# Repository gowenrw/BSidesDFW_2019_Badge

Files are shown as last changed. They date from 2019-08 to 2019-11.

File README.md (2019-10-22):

# BSidesDFW_2019_Akira_Badge

This is where all the files for the BSidesDFW 2019 Akira Badge will be stored.  
This includes code and art and cad and fab files.  All the things.

## File Structure

This is the file structure of this repository

* [/](/README.md) - YOU ARE HERE
* [/eda/](./eda/) - Electronic Design Automation files for the badge PCB (EDA is KiCad)
  * ./BSidesDFW_2019/ - KiCad 5.x project folder for the BSidesDFW 2019 badge
  * ./HHV_2019_SC/ - KiCad 5.x project folder for the HHV Soldering Challenge board
  * ./CH552G_dev_board/ - KiCad 5.x project folder for the CH552G development board
* [/code/](./code/) - Code for programming the badge
  * ./BSidesDFW_badge/ - Code for the BSidesDFW_2019_Badge
  * ./CH552G_dev_board/ - Code for the CH552G dev board
  * ./CH552T_dev_board/ - Code for the CH552T dev board designed by WrickertH552    
  * ./ugly_dev_board/ - Code for the Ugly Dev Board CH552 Proof of Concept
  * ./include/ - Includes for the 55X chipset used in all the above
* [/docs/](./docs/) - Documentation created by this project related to the badge
* [/graphics/](./graphics/) - Artwork and other graphics created by this project for the badge
* [/reference/](./reference/) - Documentation pulled from other sources related to the badge components
  * ./battery-holder/ - Reference Materials related to battery holders.
  * ./button/ - Reference Materials related to buttons.
  * ./capacitor/ - Reference Materials related to capacitors.
  * ./ch55x/ - Reference Materials related to the CH55x micro-controller.
  * ./LED/ - Reference Materials related to LEDs.
  * ./resistor/ - Reference Materials related to resistors.
  * ./switch/ - Reference Materials related to the switches.
  * ./USB-connector/ - Reference Materials related to USB connectors.
* ./README.md - This File
* ./LICENSE - Currently set to MIT but open to changing it

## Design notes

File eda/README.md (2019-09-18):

# BSidesDFW_2019_Badge / Electronic Design Automation

This is where all the Electronic Design Automation files for the badge PCB will be stored.
The EDA used for this badge is KiCad 5.x

The KiCad projects have been configured to use local libraries for long term sustainability per the best practices listed [HERE](https://hackaday.com/2017/05/18/kicad-best-practises-library-management/) and elsewhere.

## File Structure

This is the file structure of this repository

* [/](/README.md) - Home
* [/eda](/eda/) - YOU ARE HERE
  * [/eda/BSidesDFW_2019/](/eda/BSidesDFW_2019/) - KiCad 5.x project folder for the BSidesDFW 2019 badge
    * ./3d_models/ - This directory contains footprint 3d model files
    * ./gerber/ - This directory contains gerber formatted files for manufacturing
    * ./lib_fp/ - This directory contains footprint module directories
    * ./lib_sh/ - This directory contains schematic library files
    * ./pdf/ - This directory contains pdf prints of schematics and cad files
  * [/eda/CH552G_dev/](/eda/CH552G_dev/) - KiCad 5.x project folder for the CH552G development board
    * ./3d_models/ - This directory contains footprint 3d model files
    * ./gerber/ - This directory contains gerber formatted files for manufacturing
    * ./lib_fp/ - This directory contains footprint module directories
    * ./lib_sh/ - This directory contains schematic library files
    * ./pdf/ - This directory contains pdf prints of schematics and cad files
  * [/eda/HHV_2019_SC/](/eda/HHV_2019_SC/) - KiCad 5.x project folder for the HHV Soldering Challenge board
    * ./3d_models/ - This directory contains footprint 3d model files
    * ./gerber/ - This directory contains gerber formatted files for manufacturing
    * ./lib_fp/ - This directory contains footprint module directories
    * ./lib_sh/ - This directory contains schematic library files
    * ./pdf/ - This directory contains pdf prints of schematics and cad files

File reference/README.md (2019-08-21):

# BSidesDFW_2019_Badge / Reference

Documentation pulled from other sources related to the badge components

## File Structure

This is the file structure of this repository

* [/](/README.md) - Home
* [/reference/](/reference/) - YOU ARE HERE
  * [/reference/battery-holder/](/reference/battery-holder/) - Reference Materials related to battery holders.
  * [/reference/button/](/reference/button/) - Reference Materials related to buttons.
  * [/reference/capacitor/](/reference/capacitor/) - Reference Materials related to capacitors.
  * [/reference/ch55x/](/reference/ch55x/) - Reference Materials related to the CH55x micro-controller.
  * [/reference/LED/](/reference/LED/) - Reference Materials related to LEDs.
  * [/reference/resistor/](/reference/resistor/) - Reference Materials related to resistors.
  * [/reference/switch/](/reference/switch/) - Reference Materials related to the switches.
  * [/reference/USB-connector/](/reference/USB-connector/) - Reference Materials related to USB connectors.

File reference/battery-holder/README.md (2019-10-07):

# BSidesDFW_2019_Badge / Reference / Battery Holders

Battery Holders tested and the one chose for use with the badge.

## File Structure

This is the file structure of this repository

* [/](/README.md) - Home
* [/reference/](/reference/) - Documentation pulled from other sources related to the badge components
  * [/reference/battery-holder/](/reference/battery-holder/) - YOU ARE HERE

## Reference Files

* 3xAAA/No.7 Battery Box with lead wires
  * Tested and CHOSEN for the badge as it provided the needed voltage and stored power
  * [LCSC.COM Reference](./MIC-No-7-Battery-3Section-side-by-side-battery-box-Line-length150mm_C9091_lcsc.com.pdf)
  * [Datasheet](./MIC-No-7-Battery-3Section-side-by-side-battery-box-Line-length150mm_C9091_datasheet.pdf)
* CR2032 Battery Holder SMD
  * Tested and NOT chosen as it did not provide enough voltage and stored power for the badge
  * [LCSC.COM Reference](./Q-J-CR2032-BS-6-1_C70377_lcsc.com.pdf)
  * [Datasheet](./Q-J-CR2032-BS-6-1_C70377_datasheet.pdf)
* CR2032 Battery Holder THT
  * Tested and NOT chosen as it did not provide enough voltage and stored power for the badge
  * [LCSC.COM Reference](./Q-J-CR2032-BS-2-1_C70376_lcsc.com.pdf)
  * [Datasheet](./Q-J-CR2032-BS-2-1_C70376_datasheet.pdf)
  * [SamacSys EDA Schematic/Footprint/Model](./Q-J-CR2032-BS-2-1_LIB.zip)

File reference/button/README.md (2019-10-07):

# BSidesDFW_2019_Badge / Reference / Buttons

Buttons a.k.a Tactile Switches tested and the one chose for use with the badge.

## File Structure

This is the file structure of this repository

* [/](/README.md) - Home
* [/reference/](/reference/) - Documentation pulled from other sources related to the badge components
  * [/reference/button/](/reference/button/) - YOU ARE HERE

## Reference Files

* Shou Han TS2306A Micro Switch
  * Tested and CHOSEN for the badge as it's small form factor and simple design made it perfect for the badge
  * [LCSC.COM Reference](./1904241742_SHOU-HAN-TS2306A-240gf-MSM-9_C388290_lcsc.com.pdf)
  * [Datasheet](./1904241742_SHOU-HAN-TS2306A-240gf-MSM-9_C388290_datasheet.pdf)
  * [SamacSys EDA Schematic/Footprint/Model](./LIB_TS2306A-240GF-MSM-9_C388290.zip)
* Bright TSA363G25 Tactile Switch
  * Tested and NOT chosen as it's larger form factor was not a good fit
  * [LCSC.COM Reference](./1904261730_BRIGHT-TSA363G25-250B_C354943_lcsc.com.pdf)
  * [Datasheet](./1904261730_BRIGHT-TSA363G25-250B_C354943_datasheet.pdf)
* Shou Han THT Tactile Switch
  * Tested and NOT chosen as it's larger form factor was not a good fit
  * [LCSC.COM Reference](./1905211531_SHOU-HAN-TS665CJ_C393938_lcsc.com.pdf)
  * [Datasheet](./1905211531_SHOU-HAN-TS665CJ_C393938_datasheet.pdf)

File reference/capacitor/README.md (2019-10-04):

# BSidesDFW_2019_Badge / Reference / Buttons

Capacitors tested and the one chose for use with the badge.

## File Structure

This is the file structure of this repository

* [/](/README.md) - Home
* [/reference/](/reference/) - Documentation pulled from other sources related to the badge components
  * [/reference/capacitor/](/reference/capacitor/) - YOU ARE HERE

## Reference Files

* Walsin Tech Corp 1206 100nF (0.1uF)
  * Tested and CHOSEN for the badge as it's form factor and capacitance works for the badge
  * [LCSC.COM Reference](./1811301232_Huaxin-S-T-1206B104K251CT_C338139_100nF_lcsc.com.pdf)
  * [Datasheet](./1811301232_Huaxin-S-T-1206B104K251CT_C338139_100nF_datasheet.pdf)
* CCTC 0805 100nF (0.1uF)
  * Tested and NOT chosen as it's smaller form factor was not a good fit
  * [LCSC.COM Reference](./1901071511_CCTC-TCC0805X7R104M500DT_C360619_lcsc.com.pdf)
  * [Datasheet](./1901071511_CCTC-TCC0805X7R104M500DT_C360619_datasheet.pdf)
* Walsin Tech Corp 1206 1uF
  * Tested and NOT chosen as it's capacitance was much higher than required
  * [LCSC.COM Reference](./Huaxin-S-T-1206B105K160_C152974_lcsc.com.pdf)
  * [Datasheet](./Huaxin-S-T-1206B105K160_C152974_datasheet.pdf)

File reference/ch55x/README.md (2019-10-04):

# BSidesDFW_2019_Badge / Reference / CH55x

Reference Materials related to the CH55x micro-controller.

## File Structure

This is the file structure of this repository

* [/](/README.md) - Home
* [/reference/](/reference/) - Documentation pulled from other sources related to the badge components
  * [/reference/ch55x/](/reference/ch55x/) - YOU ARE HERE

## Information

Basics on the CH551:
* 8051 Kernel with most standard registers, commands etc. only 10-15x
* Integrated oscillator up to 24Mhz
* 3x timer
* 2x 8bit PWM
* 1x SPI master / slave
* 2x UART
* 4x ADC 8bit
* 6x touch input
* 16K ROM
* 1K xRAM
* 256b iRAM
* Integrated 3.3V voltage regulator
* Integrated USB device
* 5V or 3.3V operation
* i2c is no problem with bitbanging

Programming is either with Keil C51 or with SDCC (links below)

## Reference Files

* Jiangsu Qin Heng CH552G
  * Tested and CHOSEN for the badge as it's form factor and pin count works for the badge
  * [LCSC.COM Reference](./1812131556_Jiangsu-Qin-Heng-CH552G_C111292_lcsc.com.pdf)
  * [Datasheet CN](./1812131556_Jiangsu-Qin-Heng-CH552G_C111292_datasheet.pdf)
  * [Datasheet EN](./1812131556_Jiangsu-Qin-Heng-CH552G_C111292_datasheet_zh-CN-en-Translated.pdf)
* Jiangsu Qin Heng CH552T
  * Tested and NOT chosen as it's smaller form factor was not a good fit
  * [LCSC.COM Reference](./Jiangsu-Qin-Heng-CH552T_C111367_lcsc.com.pdf)
  * [Datasheet CN](./Jiangsu-Qin-Heng-CH552T_C111367_datasheet.pdf)
  * [Datasheet EN](./Jiangsu-Qin-Heng-CH552T_C111367.zh-CN.en.pdf)

## External References

* [Hackaday article on CH552](https://hackaday.com/tag/ch552/)
* [Blog site with details on CH552](http://atcnetz.blogspot.com/2019/02/ch552-020-mikrocontroller-mit-usb.html)
* [CH55X Android Programmer](https://play.google.com/store/apps/details?id=com.atcnetz.de.ch55xprogrammer)
* [ARM KEIL C51 DEV Tools](http://www.keil.com/c51/)
* [CH554 software development kit for SDCC](https://github.com/Blinkinlabs/ch554_sdcc)
* [Small Device C Compiler SDCC](https://sourceforge.net/projects/sdcc/files/latest/download?source=files)
* [WCHISPTool Firmware Uploader](http://wch.cn/download/WCHISPTool_Setup_exe.html)
* [lcsc.com WCH products](https://lcsc.com/products/WCH_11013.html)

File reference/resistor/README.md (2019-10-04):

# BSidesDFW_2019_Badge / Reference / Resistors

Resistors tested and the ones chosen for use with the badge.

## File Structure

This is the file structure of this repository

* [/](/README.md) - Home
* [/reference/](/reference/) - Documentation pulled from other sources related to the badge components
  * [/reference/resistor/](/reference/resistor/) - YOU ARE HERE

## Reference Files

Note that we were looking for two different resistor applications.
The first needed to be 10k Ohm for use as a pull up resistor to put the IC into programming mode.
The second considered several different resistance values for best use with the LED's being considered.

### Pull up resistors

* Walsin Tech Corp WR12X103 JTL 1206 10K Ohm 1/4 Watt Resistor
  * Tested and CHOSEN for the badge as it's form factor and Watt rating is perfect for the badge
  * [LCSC.COM Reference](./1904031205_Walsin-Tech-Corp-10KR-103-5_C384031_1206_10kohm_025W_lcsc.com.pdf)
  * [Datasheet](./1904031205_Walsin-Tech-Corp-10KR-103-5_C384031_1206_10kohm_025W_datasheet.pdf)
* Vishay Intertech CRCW120610K0FKEA 1206 10K Ohm 3/4 Watt Resistor
  * Tested and NOT chosen as it's larger size due to an unneeded larger Wattage was not a good fit
  * [LCSC.COM Reference](./Vishay-Intertech-CRCW120610K0FKEA_C242483_1206_10kohm_075W_lcsc.com.pdf)
  * [Datasheet](./Vishay-Intertech-CRCW120610K0FKEA_C242483_1206_10kohm_075W_datasheet.pdf)
* Uniroyal Elec 0805W8F1002T5E 0805 10K Ohm 1/8 Watt Resistor
  * Tested and NOT chosen as it's smaller form factor was not a good fit
  * [LCSC.COM Reference](./Uniroyal-Elec-0805W8F1002T5E_C17414_0805_10kohm_0125W_lcsc.com.pdf)
  * [Datasheet](./Uniroyal-Elec-0805W8F1002T5E_C17414_0805_10kohm_0125W_datasheet.pdf)

### LED resistors

* Walsin Tech Corp WR12X331 JTL 1206 330 Ohm 1/4 Watt Resistor
  * Tested and CHOSEN for the badge as it's form factor and resistance is perfect for the badge
  * [LCSC.COM Reference](./1904031131_Walsin-Tech-Corp-330R-331-5_C383978_1206_330ohm_lcsc.com.pdf)
  * [Datasheet](./1904031131_Walsin-Tech-Corp-330R-331-5_C383978_1206_330ohm_datasheet.pdf)
* Walsin Tech Corp WR12X221 JTL 1206 220 Ohm 1/4 Watt Resistor
  * Tested and NOT chosen as it's smaller resistance had the LEDs a bit too bright for the badge
  * [LCSC.COM Reference](./1904031110_Walsin-Tech-Corp-220R-221-5_C383998_1206_220ohm_lcsc.com.pdf)
  * [Datasheet](./1904031110_Walsin-Tech-Corp-220R-221-5_C383998_1206_220ohm_datasheet.pdf)
* Uniroyal Elec 1206W4J0201T5E 1206 200 Ohm 1/4 Watt Resistor
  * Tested and NOT chosen as it's smaller resistance had the LEDs a bit too bright for the badge
  * [LCSC.COM Reference](./Uniroyal-Elec-1206W4J0201T5E_C25361_1206_200ohm_lcsc.com.pdf)
  * [Datasheet](./Uniroyal-Elec-1206W4J0201T5E_C25361_1206_200ohm_datasheet.pdf)
* Uniroyal Elec 0805W8J0331T5E 0805 330 Ohm 1/8 Watt Resistor
  * Tested and NOT chosen as it's smaller form factor was not a good fit
  * [LCSC.COM Reference](./Uniroyal-Elec-0805W8J0331T5E_C25306_0805_330ohm_lcsc.com.pdf)
  * [Datasheet](./Uniroyal-Elec-0805W8J0331T5E_C25306_0805_330ohm_datasheet.pdf)

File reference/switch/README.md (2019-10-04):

# BSidesDFW_2019_Badge / Reference / Switches

Toggle Switches tested and the one chose for use with the badge.

## File Structure

This is the file structure of this repository

* [/](/README.md) - Home
* [/reference/](/reference/) - Documentation pulled from other sources related to the badge components
  * [/reference/switch/](/reference/switch/) - YOU ARE HERE

## Reference Files

* Korean Hroparts Elec K3-1296S-E2 Toggle Switch
  * Tested and CHOSEN for the badge as it's small form factor which was perfect for the badge
  * [LCSC.COM Reference](./Korean-Hroparts-Elec-K3-1296S-E2_C136659_lcsc.com.pdf)
  * [Datasheet](./Korean-Hroparts-Elec-K3-1296S-E2_C136659_datasheet.pdf)
  * [SamacSys EDA Schematic/Footprint/Model](./LIB_K3-1296S-E2.zip)
* Korean Hroparts Elec SK-12D02-VG3 Toggle Switch
  * Tested and NOT chosen as it's larger form factor was not a good fit
  * [LCSC.COM Reference](./Korean-Hroparts-Elec-SK-12D02-VG3_C136723_lcsc.com.pdf)
  * [Datasheet](./Korean-Hroparts-Elec-SK-12D02-VG3_C136723_datasheet.pdf)

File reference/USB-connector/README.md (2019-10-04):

# BSidesDFW_2019_Badge / Reference / Switches

USB connectors tested and the one chose for use with the badge.

## File Structure

This is the file structure of this repository

* [/](/README.md) - Home
* [/reference/](/reference/) - Documentation pulled from other sources related to the badge components
  * [/reference/USB-connector/](/reference/USB-connector/) - YOU ARE HERE

## Reference Files

* Jing Extension of the Electronic Co. micro 5PAll unguided posts with flat welding
  * Tested and CHOSEN for the badge as it's flat form factor which was perfect for the badge
  * [LCSC.COM Reference](./JEEC-LCSC-micro-5PAll-posts-are-not-guided-Flat-welding-High-temperature_C77238_lcsc.com.pdf)
  * [Datasheet](./JEEC-LCSC-micro-5PAll-posts-are-not-guided-Flat-welding-High-temperature_C77238_datasheet.pdf)
* Jing Extension of the Electronic Co. MICRO USB 5S B Type horns
  * Tested and NOT chosen as it's form factor including horns was not a good fit
  * [LCSC.COM Reference](./JEEC-LCSC-MICRO-USB-5S-B-Type-horns-High-temperature_C10418_lcsc.com.pdf)
  * [Datasheet](./JEEC-LCSC-MICRO-USB-5S-B-Type-horns-High-temperature_C10418_datasheet.pdf)

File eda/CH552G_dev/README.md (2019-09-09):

# BSidesDFW_2019_Badge / Electronic Design Automation / CH552G Prototype

This is where all the KiCad 5.x files related to the CH552G prototype PCB

Note that this prototype is specific to the CH552G chip which is SOP-16 and will not work on the CH552T chip which is TSSOP-20.

## File Structure

This is the file structure of this repository

* [/](/README.md) - Home
* [/eda](/eda/) - Electronic Design Automation files for the badge PCB (EDA is KiCad)
  * [/eda/CH552G_dev/](/eda/CH552G_dev/) - YOU ARE HERE
    * ./<filename>.pro - project file. Holds parameters that apply to the entire project (schematic and PCB layout).
    * ./<filename>.sch - schematic file.
    * ./<filename>.kicad_pcb - the new PCB layout file.
    * ./<filename>.net - netlist in "Pcbnew" format
    * ./<filename>.bak - backup of schematic file.
    * ./<filename>.kicad_pcb-bak - backup of the new PCB layout file.
    * ./<filename>-cache.lib - a local cache copy of all the symbols used in the schematic
    * ./fp-lib-table - Footprint library list
    * ./sym-lib-table - Schematic library list
    * [./3d_models/](/eda/CH552G_dev/3d_models/) - This directory contains footprint 3d model files
    * [./gerber/](/eda/CH552G_dev/gerber/) - This directory contains gerber formatted files for manufacturing
    * [./lib_fp/](/eda/CH552G_dev/lib_fp/) - This directory contains footprint module directories
    * [./lib_sh/](/eda/CH552G_dev/lib_sh/) - This directory contains schematic library files
    * [./pdf/](/eda/CH552G_dev/pdf/) - This directory contains pdf prints of schematics and cad files

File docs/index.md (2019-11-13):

---
layout: default
---

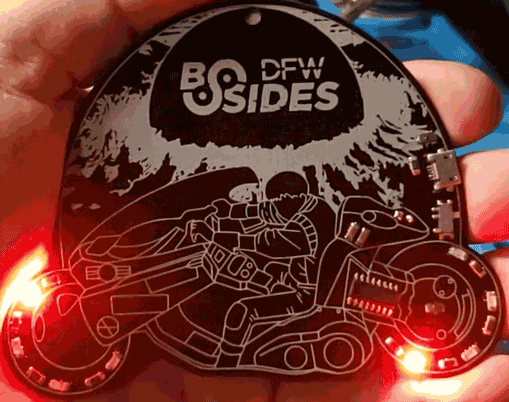
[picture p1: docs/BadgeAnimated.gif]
Hero Image


# AKIRA Badge

Welcome to the AKIRA Badge website.

Home to all the information related to the BSidesDFW 2019 AKIRA Badge.  
This includes code and art and cad and fab files.  All the things.

This is also where you will find resources and examples for working with the CH552G micro-controller that is at the heart of this badge.

Please allow me to be your guide.

-- [@alt_bier](https://twitter.com/alt_bier)  - [My Contact Info](https://gowen.net/about)

---

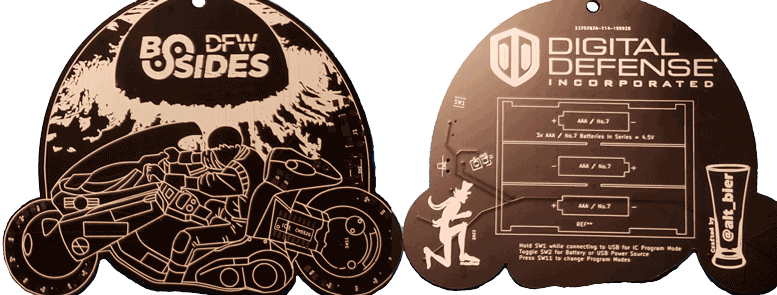
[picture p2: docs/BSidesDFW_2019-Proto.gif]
Prototype Image


# Badge Details

## Concept

When @0isac0 brought up the idea of an AKIRA themed badge with something to do with that infamous bike I loved it.
He wanted to do a theme related to a movie set in 2019 and I had just made a Blade Runner themed badge for DC27.
So, AKIRA was the next logical choice.

We were originally toying with the idea of having the bike viewed tail on so that we could showcase the back of Kaneda's jacket.
But then I had the idea of using LEDs on the tires to give the illusion that the bike was in motion.

I also wanted to get some of the darker themes of the movie into the badge.
So, having Kaneda be driving his bike past the destruction of Neo-Tokyo seemed like the perfect fit.

I managed to get the explosion artwork and the bike outline completed when I hit a snag.
While I can do technical drawings, I just can't draw people and was really struggling with Kaneda on the bike.
Luckily, @unspecific came to the rescue with some awesome artwork to complete the badge.

## CH552G Micro-Controller

The CH552G is the inexpensive micro-controller that is at the heart of this badge.
It has been highlighted on [Hackaday](https://hackaday.com/tag/ch552/) and elsewhere as a great option for hardware projects.

However, when designing this badge I found there were limited resources available online for this chip as opposed to other more popular and expensive chips.
So, hopefully this repository can help future users of this great micro-controller.

## Surface Mount Components

While I have toyed with surface mount components in several projects, this is the first badge I have designed using them.
This was a challenge that I enjoyed tackling.
However, it did pose one major problem: soldering.

While my little hot air solder gun works fine to reflow SMD's on a project PCB here or there, it does not scale to hundreds.

Luckily, @leetnet was kind enough to loan me an industrial reflow oven.
This let us reflow the badges in the larger quantities needed.

And by us, I mean all the great volunteers (human pick and place machines) who came out to the badge assembly parties.
We would not have been able to get it done without you!

## Lanyard

When designing the lanyard I wanted it to tie into the badge theme as well.
So, where the change to bike profile on the badge didn't let us incorporate the back of Kaneda's jacket, that iconic pill shape worked into the lanyard nicely.

Lanyard

## LED Colors

When coming up with the black and white design it was decided that we would use colored LEDs to bring it to life.
Choosing the right colors involved a lot of trial and error.
But, eventually I settled on four major colors that looked great on it: Red, Green, Yellow, and Blue.

I could not settle on a single color that I liked best.
So, I decided to use them all and make LED color the differentiation between the different badge types: Attendee (Human) - Red, Sponsor - Green, Speaker - Yellow, and Staff - Blue.

## Crypto Challenge

The AKIRA Badge included a cryptography challenge that was designed to be solved during the one day BSidesDFW 2019 conference.  

Thanks to all who participated in this challenge!

While the solution page is still active for those who are attempting to solve it after the con, the Crypto Challenge is officially over and we will not be registering new solvers.

Here is registered winner and the list of those who solved it during the BSidesDFW conference:

| Timestamp	| Name/Handle |
| --- | --- |
| 11/2/2019 09:42:15	| Malcolm @leetnet - WINNER |
| 11/2/2019 10:26:40	| jeff morales |
| 11/2/2019 11:34:17	| @hkhanes |
| 11/2/2019 11:34:28	| hiccup |
| 11/2/2019 11:34:39	| @mcwtravis |
| 11/2/2019 14:02:52	| monopole |
| 11/2/2019 14:12:15	| zarak |
| 11/2/2019 14:18:32	| Wheatley |
| 11/2/2019 14:33:49	| M0r1 |
| 11/2/2019 14:34:54	| Lowkey |
| 11/2/2019 14:35:42	| Aggie_r3c0n |
| 11/2/2019 15:19:55	| Spdrstar |
| 11/2/2019 17:31:32	| 17:31 |

[Click this link for details about the cryptography challenge including the complete solution](crypto.html).

## Sponsor

I wanted to thank this years badge sponsor [Digital Defense Incorporated](https://www.digitaldefense.com/) for their generous sponsorship that made this years badge possible.

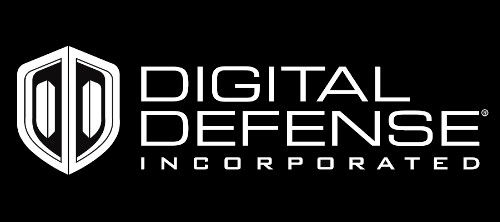
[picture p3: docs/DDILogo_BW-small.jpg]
DDI


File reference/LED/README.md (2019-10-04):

# BSidesDFW_2019_Badge / Reference / LEDs

LEDs tested and the ones chosen for use with the badge.

## File Structure

This is the file structure of this repository

* [/](/README.md) - Home
* [/reference/](/reference/) - Documentation pulled from other sources related to the badge components
  * [/reference/LED/](/reference/LED/) - YOU ARE HERE

## Reference Files

* TOGIALED 1206 Green
  * Tested and CHOSEN for the badge as form factor and component markings and brightness were all perfect
  * [LCSC.COM Reference](TOGIALED-TJ-S3216SW9TGLC2G-A5_C192678_1206_green_lcsc.com.pdf)
  * [Datasheet](TOGIALED-TJ-S3216SW9TGLC2G-A5_C192678_1206_green_datasheet.pdf)
* TOGIALED 1206 Red
  * Tested and CHOSEN for the badge as form factor and component markings and brightness were all perfect
  * [LCSC.COM Reference](TOGIALED-TJ-S3216SW9TGLC2R-A5_C192674_1206_red_lcsc.com.pdf)
  * [Datasheet](TOGIALED-TJ-S3216SW9TGLC2R-A5_C192674_1206_red_datasheet.pdf)
* TOGIALED 1206 Blue
  * Tested and CHOSEN for the badge as form factor and component markings and brightness were all perfect
  * [LCSC.COM Reference](TOGIALED-TJ-S3216SW9TGLC6B-A5_C192679_1206_blue_lcsc.com.pdf)
  * [Datasheet](TOGIALED-TJ-S3216SW9TGLC6B-A5_C192679_1206_blue_datasheet.pdf)
* TOGIALED 1206 Yellow
  * Tested and CHOSEN for the badge as form factor and component markings and brightness were all perfect
  * [LCSC.COM Reference](TOGIALED-TJ-S3216SW9TGLC9Y-A5_C192676_1206_yellow_lcsc.com.pdf)
  * [Datasheet](TOGIALED-TJ-S3216SW9TGLC9Y-A5_C192676_1206_yellow_datasheet.pdf)
* Everlight Elec 0805 Red
  * Tested and NOT chosen as it was not a good fit
  * [LCSC.COM Reference](Everlight-Elec-17-21SURC-S530-A2-TR8_C131244_0805_red_lcsc.com.pdf)
  * [Datasheet](Everlight-Elec-17-21SURC-S530-A2-TR8_C131244_0805_red_datasheet.pdf)
* Foshan NationStar Optoelectronics 0805 Orange
  * Tested and NOT chosen as it was not a good fit
  * [LCSC.COM Reference](Foshan-NationStar-Optoelectronics-FC-2012YOXK-5-600H08_C84262_0805_orange_lcsc.com.pdf)
  * [Datasheet](Foshan-NationStar-Optoelectronics-FC-2012YOXK-5-600H08_C84262_0805_orange_datasheet.pdf)
* Foshan NationStar Optoelectronics 01206 Green
  * Tested and NOT chosen as it was not a good fit
  * [LCSC.COM Reference](Foshan-NationStar-Optoelectronics-FC-3215UGK-520D_C99881_1206_green_lcsc.com.pdf)
  * [Datasheet](Foshan-NationStar-Optoelectronics-FC-3215UGK-520D_C99881_1206_green_datasheet.pdf)
* Foshan NationStar Optoelectronics 0805 White
  * Tested and NOT chosen as it was not a good fit
  * [LCSC.COM Reference](Foshan-NationStar-Optoelectronics-FC-A2012WD-457H5_C84258_0805_white_lcsc.com.pdf)
  * [Datasheet](Foshan-NationStar-Optoelectronics-FC-A2012WD-457H5_C84258_0805_white_datasheet.pdf)
* Orient 0805 Blue
  * Tested and NOT chosen as it was not a good fit
  * [LCSC.COM Reference](Orient-ORH-B35A_C205441_0805_blue_lcsc.com.pdf)
  * [Datasheet](Orient-ORH-B35A_C205441__0805_blue_datasheet.pdf)
* Orient 0805 Green
  * Tested and NOT chosen as it was not a good fit
  * [LCSC.COM Reference](Orient-ORH-G35A_C205442_0805_green_lcsc.com.pdf)
  * [Datasheet](Orient-ORH-G35A_C205442_0805_green_datasheet.pdf)
* Orient 0805 Orange
  * Tested and NOT chosen as it was not a good fit
  * [LCSC.COM Reference](Orient-ORH-R35A_C205444_0805_orange-red_lcsc.com.pdf)
  * [Datasheet](Orient-ORH-R35A_C205444_0805_orange-red_datasheet.pdf)
* Orient 0805 Green-Yellow
  * Tested and NOT chosen as it was not a good fit
  * [LCSC.COM Reference](Orient-ORH-YG35A_C205449_0805_green-yellow_lcsc.com.pdf)
  * [Datasheet](Orient-ORH-YG35A_C205449_0805_green-yellow_datasheet.pdf)

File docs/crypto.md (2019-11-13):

---
layout: default
---

Hero Image

# AKIRA Badge Crypto Challenge

The AKIRA Badge included a cryptography challenge that was designed to be solved during the one day BSidesDFW 2019 conference.  

Here is registered winner and the list of those who solved it during the BSidesDFW conference:

| Timestamp	| Name/Handle |
| --- | --- |
| 11/2/2019 09:42:15	| Malcolm @leetnet - WINNER |
| 11/2/2019 10:26:40	| jeff morales |
| 11/2/2019 11:34:17	| @hkhanes |
| 11/2/2019 11:34:28	| hiccup |
| 11/2/2019 11:34:39	| @mcwtravis |
| 11/2/2019 14:02:52	| monopole |
| 11/2/2019 14:12:15	| zarak |
| 11/2/2019 14:18:32	| Wheatley |
| 11/2/2019 14:33:49	| M0r1 |
| 11/2/2019 14:34:54	| Lowkey |
| 11/2/2019 14:35:42	| Aggie_r3c0n |
| 11/2/2019 15:19:55	| Spdrstar |
| 11/2/2019 17:31:32	| 17:31 |

Thanks to all who participated in this challenge!

Since this was the first cryptography challenge I designed, I am very happy that so many people enjoyed it and solved it.

For those who have not yet solved it yet: Spoiler Alert!  
I am going to walk through all the details of the challenge including the solution on this page.
If you are wanting to solve this challenge on your own then [TURN BACK NOW!](/)

-- [@alt_bier](https://twitter.com/alt_bier)

---

Prototype Image

# Crypto Challenge Details

## Concept

The idea of adding a crypto challenge to the badge was one that I came up with early in badge design.
This is why the badge has eight LEDs on it instead of six or ten, eight was what I wanted for the crypto challenge.

I had never done a crypto challenge before and this seemed like the perfect opportunity.
Since BSidesDFW is a one day conference the challenge would have to be simple enough for people to solve with only part time effort in one day.  
A simple challenge would be easier for me to implement, which was perfect for a first time.

I wanted to tie the challenge to the local DFW hacker community as well as to he theme of the badge which was based on the Akira anime.
You will see both these tie in's as we step through the challenge details.

## Details

Let's get into the details!

### Flashing LED Code

Let's start with the entry to the crypto challenge which is the flashing LED code that was included in the firmware on the badge.

Here is how it to get access to the special crypto challenge LED mode:
* The badges were provided to people with the LED's flashing in a circular pattern to simulate motion.
* There is a button on one of the wheels that changes the LED flashing mode.
* The first few button pushes simply slow down the LED movement.
* The fourth button push will place the badge into crypto challenge LED mode

So, now instead of LED's flashing in a circular pattern they are flashing a code.
* Most people recorded these flashed code from the badge itself to solve what they were.
* Some people found it easier to look up the firmware code in this repository to document the flashed code.

What is this code?

As stated previously, there are a total of eight LED's on the badge.
This is important because there are 8 bits to a byte, and bytes can be characters.
Specifically, ASCII characters.

The code that is being flashed on the LEDs is the binary equivalent of ASCII characters.
The LEDs when read from left to right around each tire will be ON for 1 and OFF for 0.
There is an all off period between each ASCII character being flashed with a longer all off period at the end of message before it repeats.

When compared to an ASCII to Binary table like the one shown below the code will reveal the following cipher text:
```
cbggto.kszraliuge.mwd
```

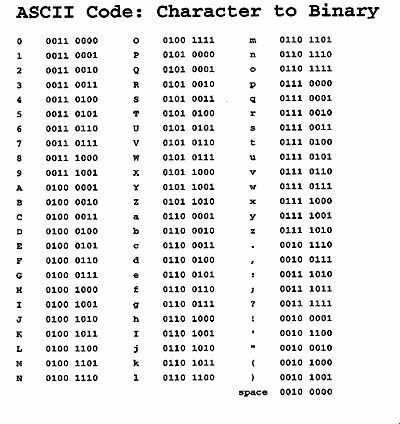
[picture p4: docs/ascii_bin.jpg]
ASCII_BINARY


### CIPHER

Once the the string of cipher text ```cbggto.kszraliuge.mwd``` is found the tasks of determining the Cipher and Key remain to be solved.
Let's focus on the Cipher first.

This is where I included a tie in to the local DFW hacker community.

At a recent [Dallas Hackers Association - DHA](https://dallashackers.com/) meeting one of our communities awesome contributors [Woody @woody2237](https://twitter.com/woody2237) gave a talk about the [Vigenère cipher](https://en.wikipedia.org/wiki/Vigen%C3%A8re_cipher) and a python program he wrote to encrypt/decrypt text using it.

So, the [Vigenère cipher](https://en.wikipedia.org/wiki/Vigen%C3%A8re_cipher) is what I decided to use for this challenge.
To make it a little easier for people to figure out during the conference, I posted a printout of the Vigenère square cipher table (shown below) on a wall in the Hardware Hacking Village with no explanation.  
The few people who asked me about it were given no further clues until the talk at 13:30 where I revealed the name of the Cipher to all who attended.

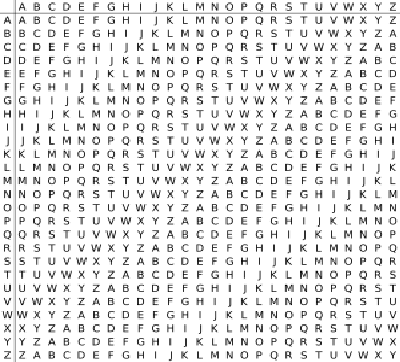
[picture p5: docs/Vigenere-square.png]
Vigenere-square


One resource that I found handy when making this challenge is the [decode.fr Vigenere cipher page](https://www.dcode.fr/vigenere-cipher).  
There are other resources like this one out there, but this is the one I used.

One important note about the cipher is that it was traditionally used with only the 26 letters of the alphabet.
This means that it is not cap sensitive and that any punctuation (periods) should be considered clear text.

### KEY

With both the cipher text and the cipher only the key remains to be solved.

This is where I included a tie in to the badge theme.

Anyone who looked at this badge would know the theme was the Akira anime.
So, to keep the challenge simple I made the key ```AKIRA``` (not cap sensitive).

Using the [Vigenère cipher](https://en.wikipedia.org/wiki/Vigen%C3%A8re_cipher) with the key ```AKIRA``` on the cipher text ```cbggto.kszraliuge.mwd``` (ignoring periods) produces the following clear text:
```
crypto.akirabadge.com
```

This is obviously a web page that the solvers will register for the win, right?

Not so fast!

### Challenge Part II

In order to prevent someone from stealing the win by getting to the solution page by other means than solving cryptography (e.g. whois/dns-lookups/etc.) I added a second part to the challenge.

This second part would have challenge participants solve a second cipher text that is provided on this page.

This next part was designed to be a very easy stop over for those who completed the first part to make it to the web page, since they would already know the cipher and the theme of the first key.

However, anyone who reached this page without solving the first part would have a difficult time since they would not know they cipher or what the first key was based on.

Here is the text from that part one solution page:

```
Congratulations!
If you are here it means that you solved the first part of the crypto challenge.
  To complete the challenge you only need to solve one more puzzle.
  This next puzzle will lead you to another web page in this domain (e.g. crypto.akirabadge.com/something/something.html).
  Note: punctuation has been purposely left out of the ciphertext. So, you will need to figure out if it is /aaa/bbb.html or /aa/ab/bb.html, etc.
  If you got to this page then you already know the cipher used for this next part. You just need to figure out the key.
  I hope you solve this as quickly as Akira drove his bike through the streets of NeoTokyo!
Challenge Part Two
  Here is the ciphertext for part two of the challenge:
  mbnmqdoxuxpl

```

This explains the cipher is the same and this is the new cipher text:
```
mbnmqdoxuxpl
```

This is provided without punctuation, but when solved will send users to another page on this site where the solvers will register for the win.

### Part II KEY

In addition to providing the cipher text that web page provided a major clue as to the key.

This line in particular was the clue:
```
I hope you solve this as quickly as Akira drove his bike through the streets of NeoTokyo!
```

Anyone who has seen Akira or googled it as part of the challenge should know that it was Kaneda and not Akira who rode that infamous bike.

So, the key is ```KANEDA```

Using the [Vigenère cipher](https://en.wikipedia.org/wiki/Vigen%C3%A8re_cipher) with the key ```KANEDA``` on the cipher text ```mbnmqdoxuxpl``` produces the following clear text:
```
cbaindexhtml
```

I kept it fairly simple to figure out where the punctuation should be added turning the clear text ```cbaindexhtml``` into the URI ```/cba/index.html```

This would make the full URL of the solution page:
```
crypto.akirabadge.com/cba/index.html
```

### Solution Page

The final solution page had the following text:
```
Congratulations!
If you are here it means that you solved the crypto challenge, or cheated.

Either way, congratulations!

Register for the Trophy
```

This final solution page then contained an embedded google form for solvers to enter their Name/Handle.
This was saved with the date/time that it was posted.
This form and it's timestamps are what was used to determine the winner.

## Thanks!

Thanks again to all who attempted this challenge.

I hope it was as much fun for you to puzzle and solve as it was for me to create.

-- [@alt_bier](https://twitter.com/alt_bier)

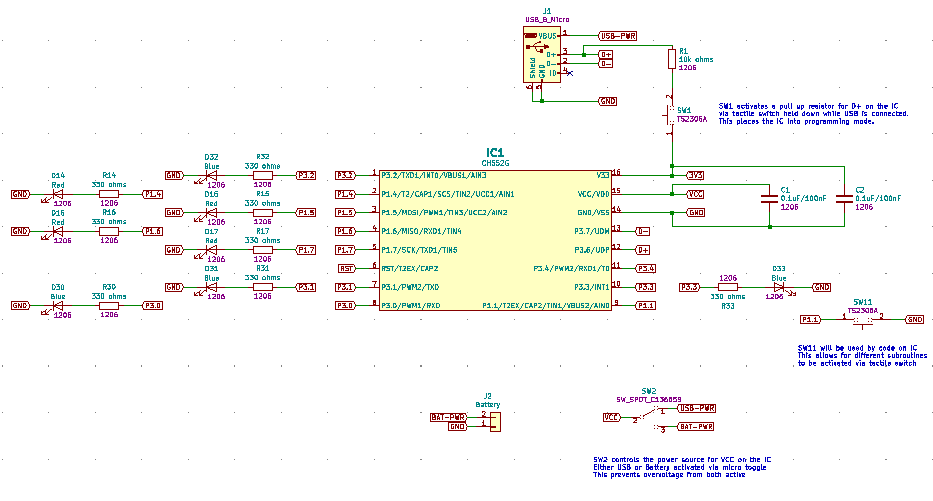
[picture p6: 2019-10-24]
eda/BSidesDFW_2019/pdf/BSidesDFW_2019_schematic.png

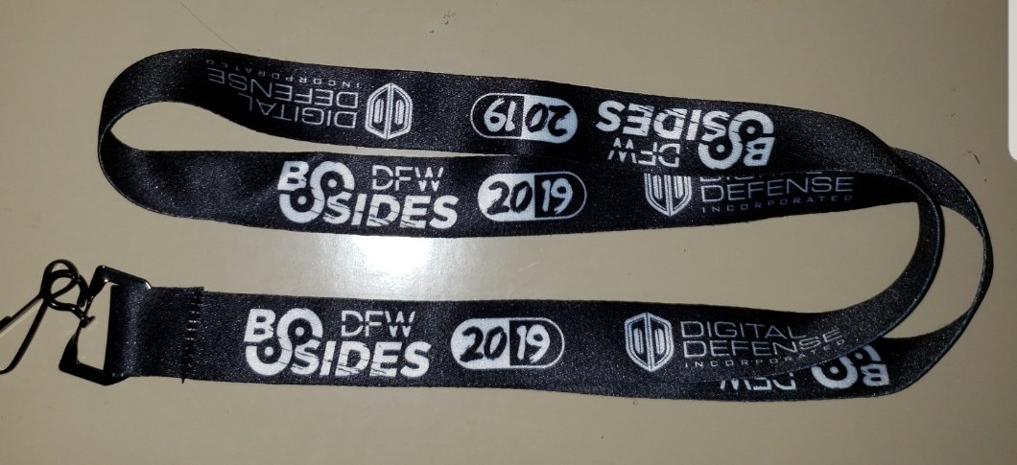
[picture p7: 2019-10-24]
docs/lanyard.jpg

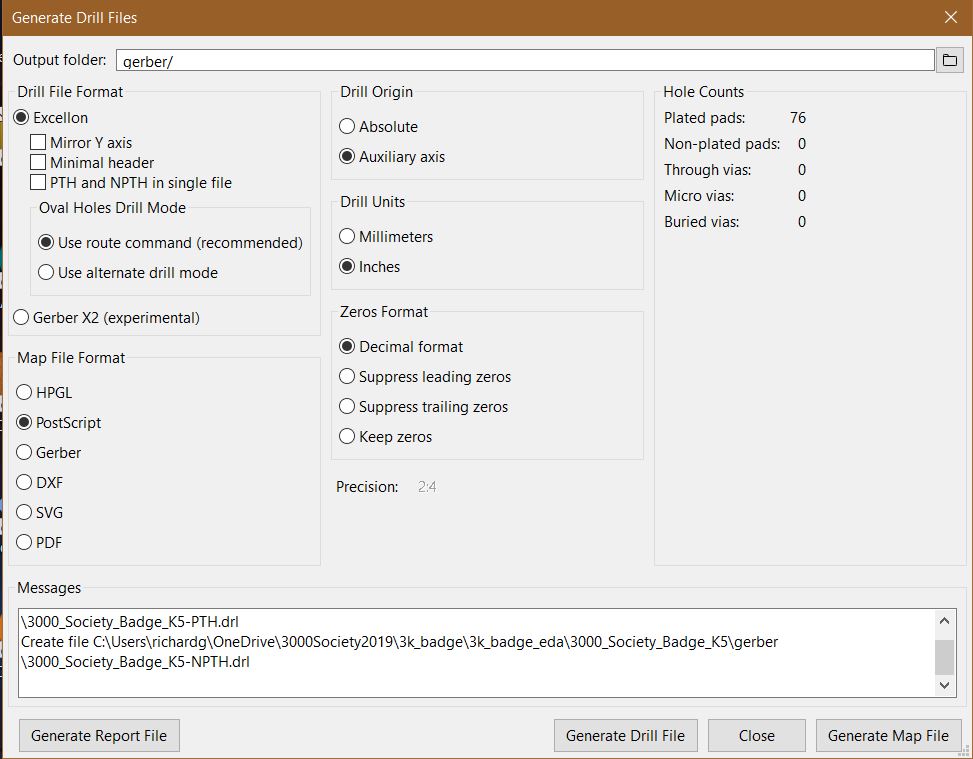
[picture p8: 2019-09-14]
eda/HHV_2019_SC/gerber/DrillSettings.JPG

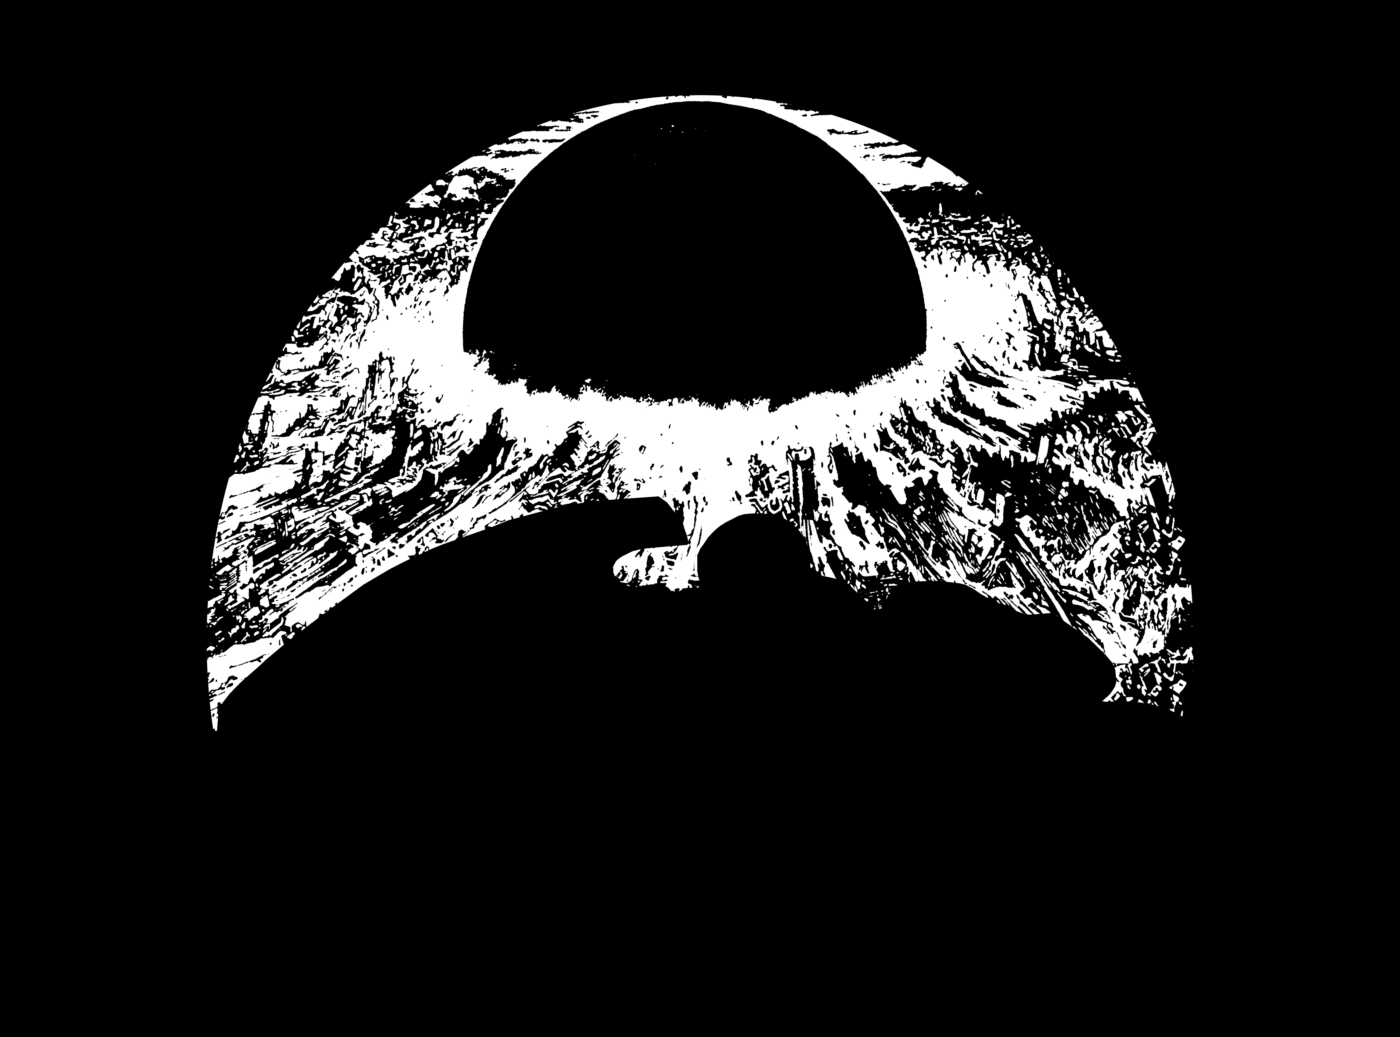
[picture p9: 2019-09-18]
graphics/Asset 4.png

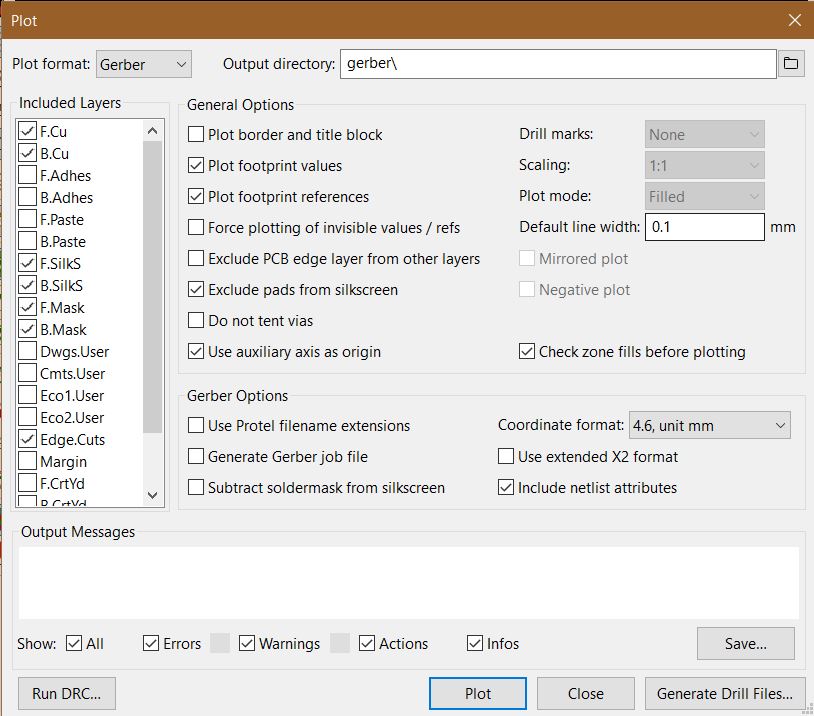
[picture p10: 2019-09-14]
eda/HHV_2019_SC/gerber/GerberSetting.JPG

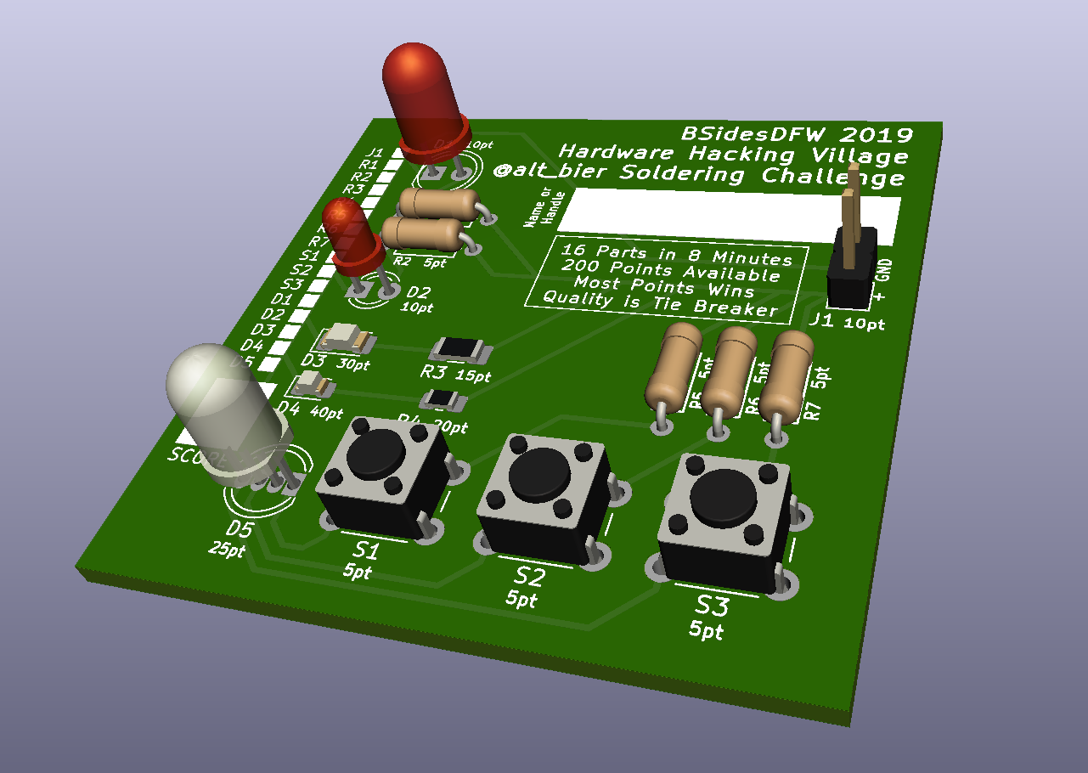
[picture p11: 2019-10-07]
eda/HHV_2019_SC/pdf/HHV_2019_SC.png

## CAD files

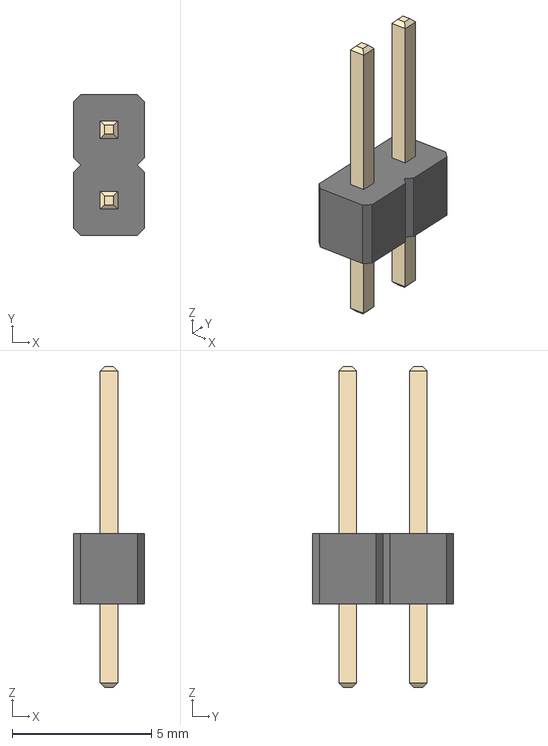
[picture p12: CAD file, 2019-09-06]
eda/BSidesDFW_2019/3d_models/PinHeader_1x02_P2.54mm_Vertical.step
2.54 x 5.08 x 11.5 mm

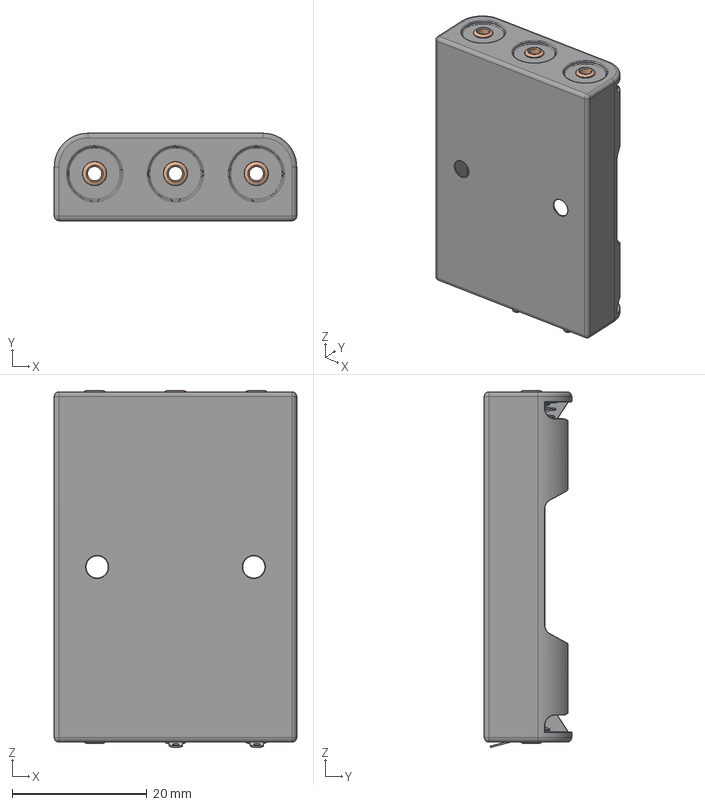
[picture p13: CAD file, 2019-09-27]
eda/HHV_2019_SC/3d_models/Battery_Holder_3xAAA_Simple.step
36.0 x 13.0 x 53.0 mm

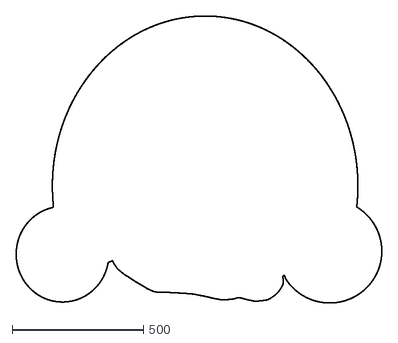
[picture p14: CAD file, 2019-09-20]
graphics/badge-edge-cuts.dxf
1393.9 x 1093.8

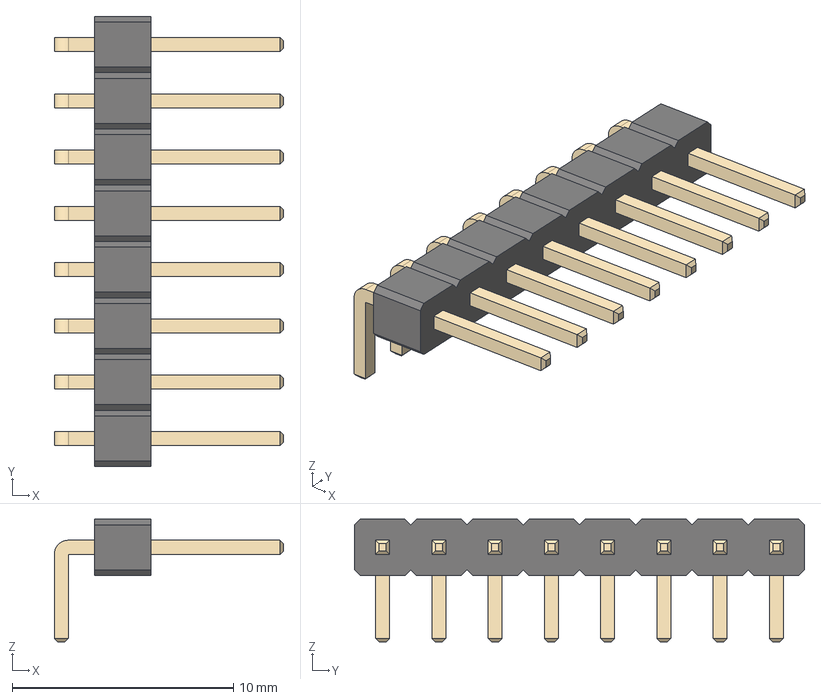
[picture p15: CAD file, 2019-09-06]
eda/BSidesDFW_2019/3d_models/PinHeader_1x08_P2.54mm_Horizontal.step
10.4 x 20.3 x 5.54 mm

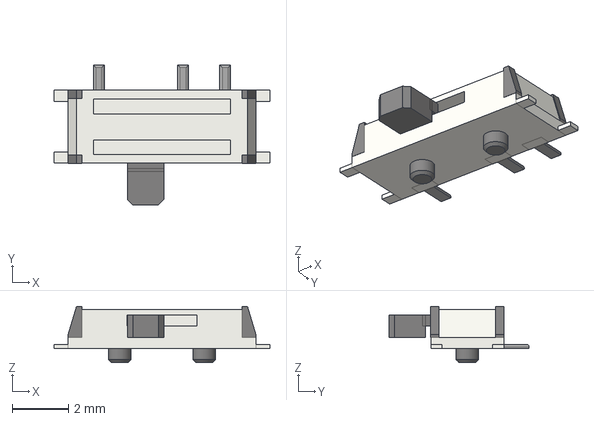
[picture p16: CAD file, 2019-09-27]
eda/HHV_2019_SC/3d_models/SW_SPDT_PCM12.step
7.70 x 5.00 x 2.00 mm

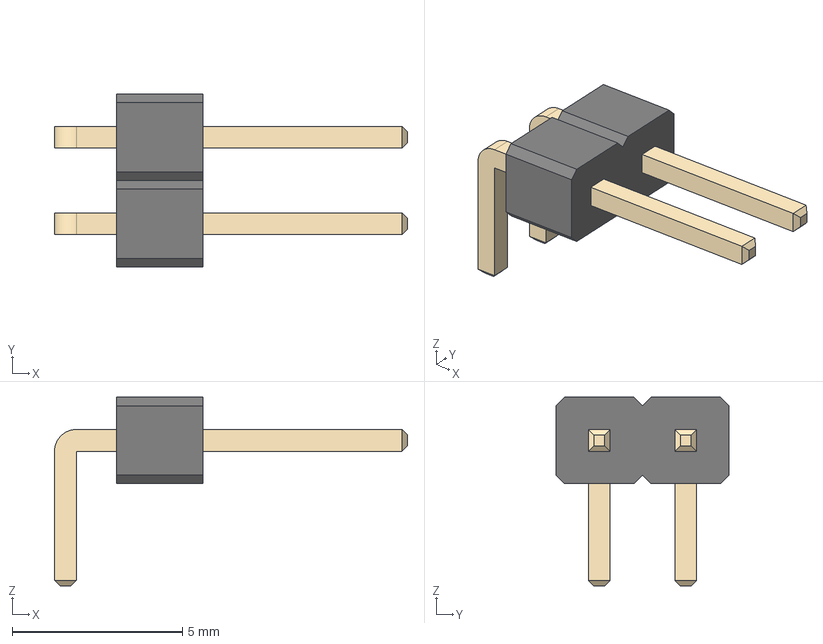
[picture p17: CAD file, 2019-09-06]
eda/BSidesDFW_2019/3d_models/PinHeader_1x02_P2.54mm_Horizontal.step
10.4 x 5.08 x 5.54 mm

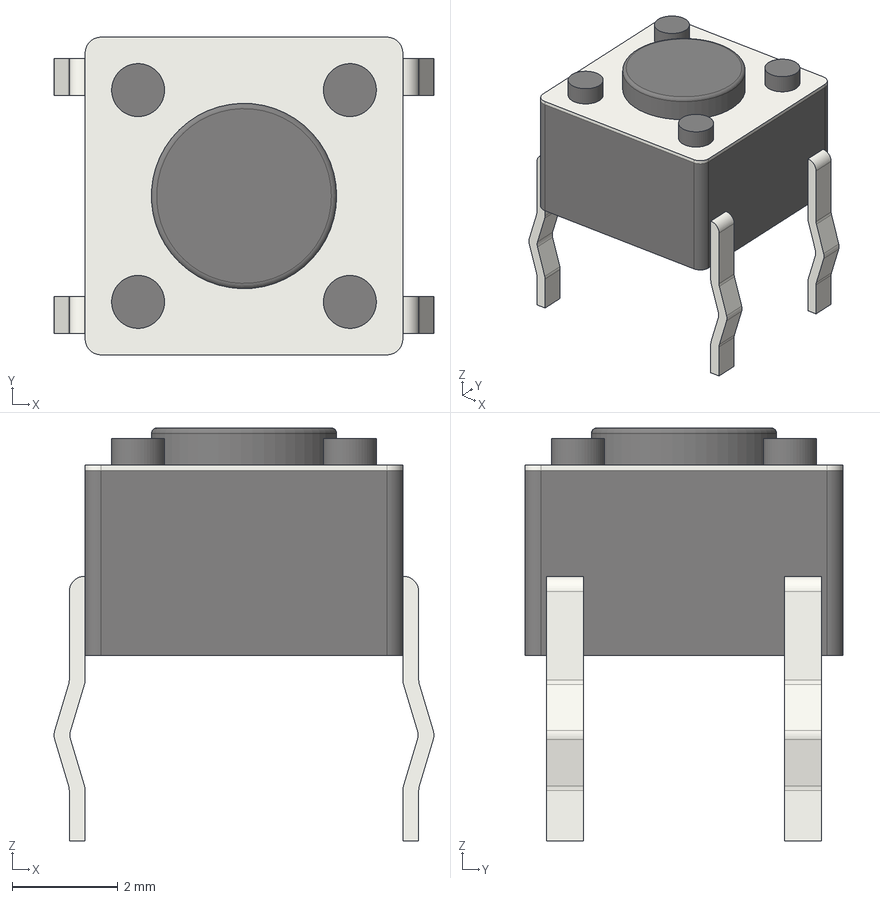
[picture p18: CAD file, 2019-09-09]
eda/HHV_2019_SC/3d_models/SW_PUSH_6mm.step
7.17 x 6.00 x 7.80 mm

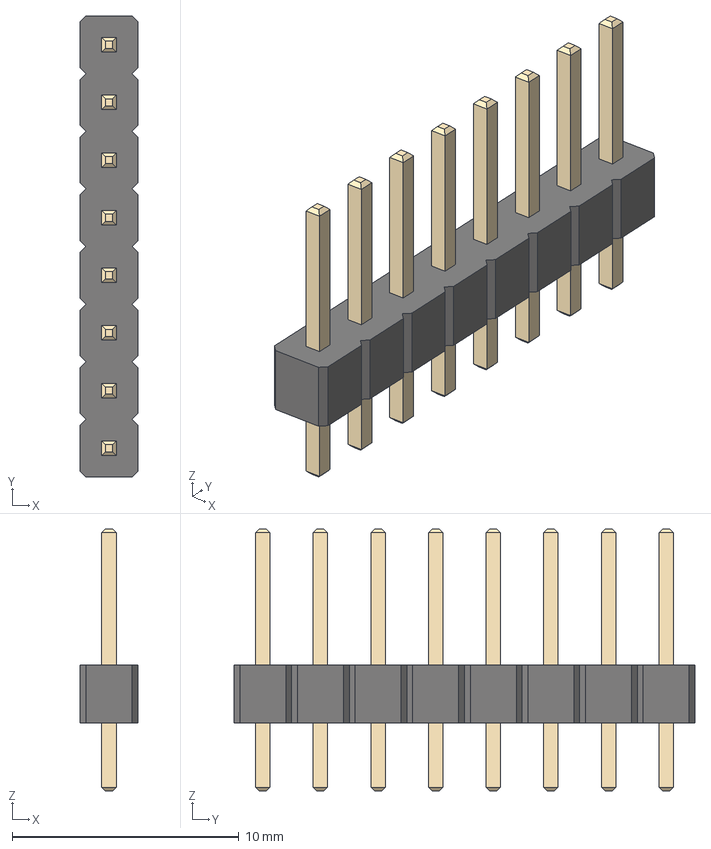
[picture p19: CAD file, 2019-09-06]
eda/BSidesDFW_2019/3d_models/PinHeader_1x08_P2.54mm_Vertical.step
2.54 x 20.3 x 11.5 mm

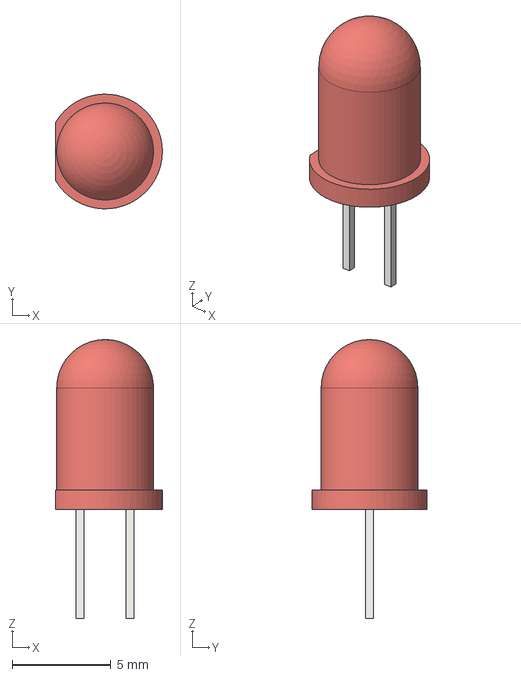
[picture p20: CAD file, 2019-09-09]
eda/HHV_2019_SC/3d_models/LED_D5.0mm.step
5.40 x 5.79 x 14.1 mm

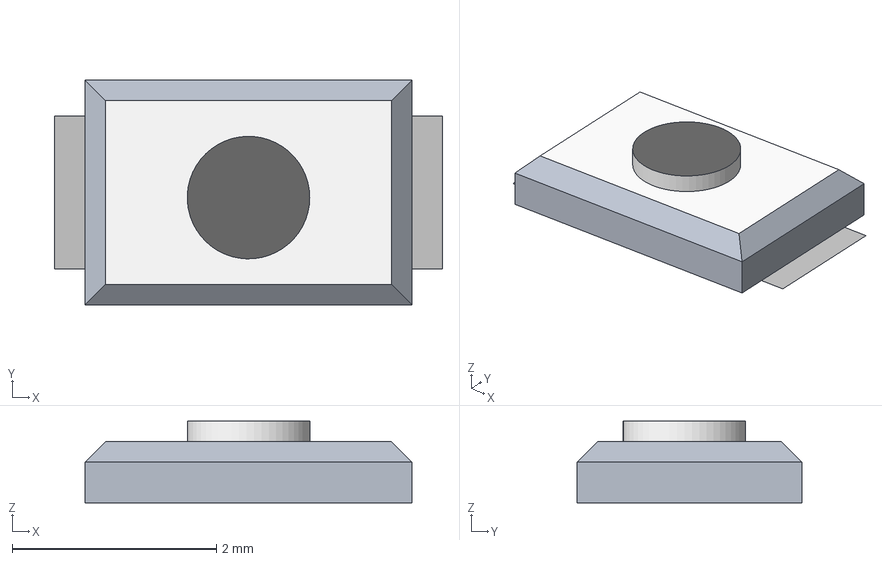
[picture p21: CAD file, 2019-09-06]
eda/BSidesDFW_2019/3d_models/TS2306A.step
3.80 x 2.20 x 0.8 mm
Plane

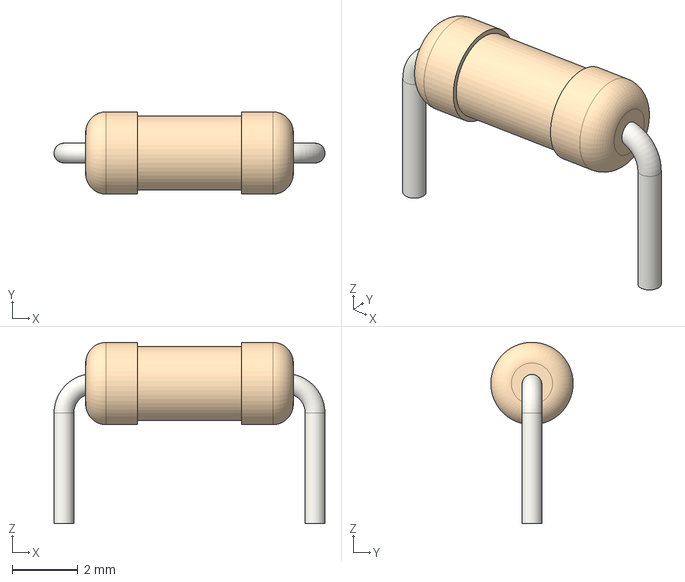
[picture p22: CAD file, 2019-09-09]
eda/HHV_2019_SC/3d_models/R_Axial_DIN0207_L6.3mm_D2.5mm_P7.62mm_Horizontal.step
8.22 x 2.50 x 5.50 mm

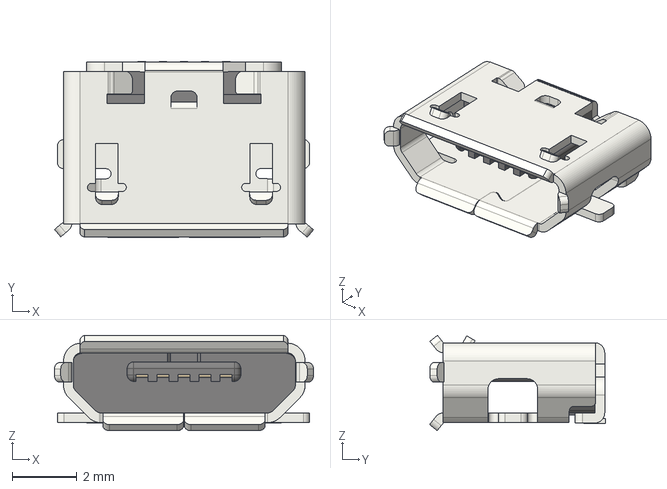
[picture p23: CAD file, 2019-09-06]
eda/BSidesDFW_2019/3d_models/USB_Micro-B_Molex_47346-0001.step
7.98 x 5.42 x 2.94 mm

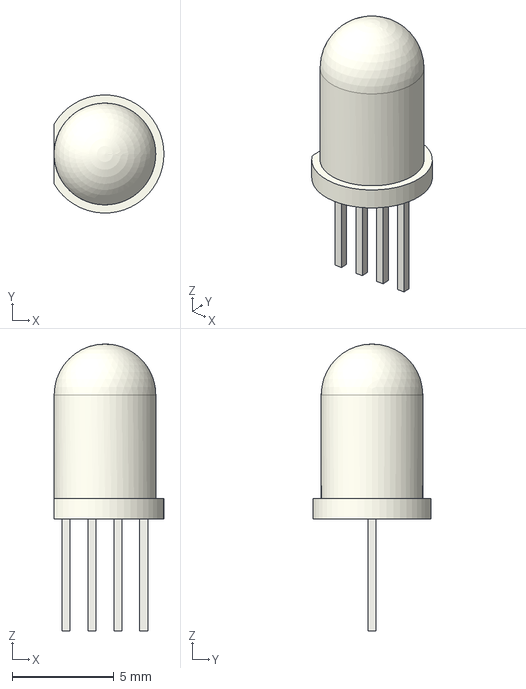
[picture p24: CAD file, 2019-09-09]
eda/HHV_2019_SC/3d_models/LED_D5.0mm-4_RGB.step
5.40 x 5.79 x 14.1 mm

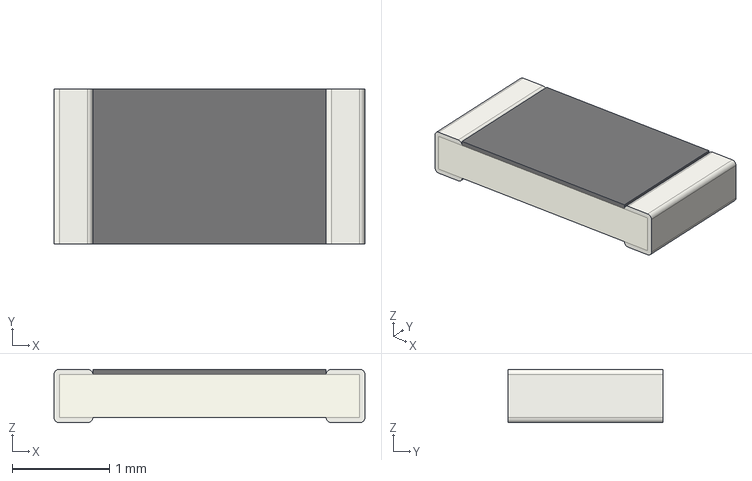
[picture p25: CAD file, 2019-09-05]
eda/BSidesDFW_2019/3d_models/R_1206_3216Metric.step
3.20 x 1.60 x 0.55 mm

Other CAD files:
eda/HHV_2019_SC/3d_models/LED_D3.0mm.step
eda/BSidesDFW_2019/3d_models/LED_0805_2012Metric.step
eda/HHV_2019_SC/3d_models/LED_D8.0mm.step
eda/BSidesDFW_2019/3d_models/LED_0805_2012Metric_Castellated.step
eda/BSidesDFW_2019/3d_models/C_0805_2012Metric.step
eda/BSidesDFW_2019/3d_models/C_1206_3216Metric.step
eda/BSidesDFW_2019/3d_models/LED_1206_3216Metric.step
eda/BSidesDFW_2019/3d_models/LED_1206_3216Metric_Castellated.step
eda/BSidesDFW_2019/3d_models/R_0805_2012Metric.step
eda/BSidesDFW_2019/3d_models/SOIC-16_3.9x9.9mm_P1.27mm.step

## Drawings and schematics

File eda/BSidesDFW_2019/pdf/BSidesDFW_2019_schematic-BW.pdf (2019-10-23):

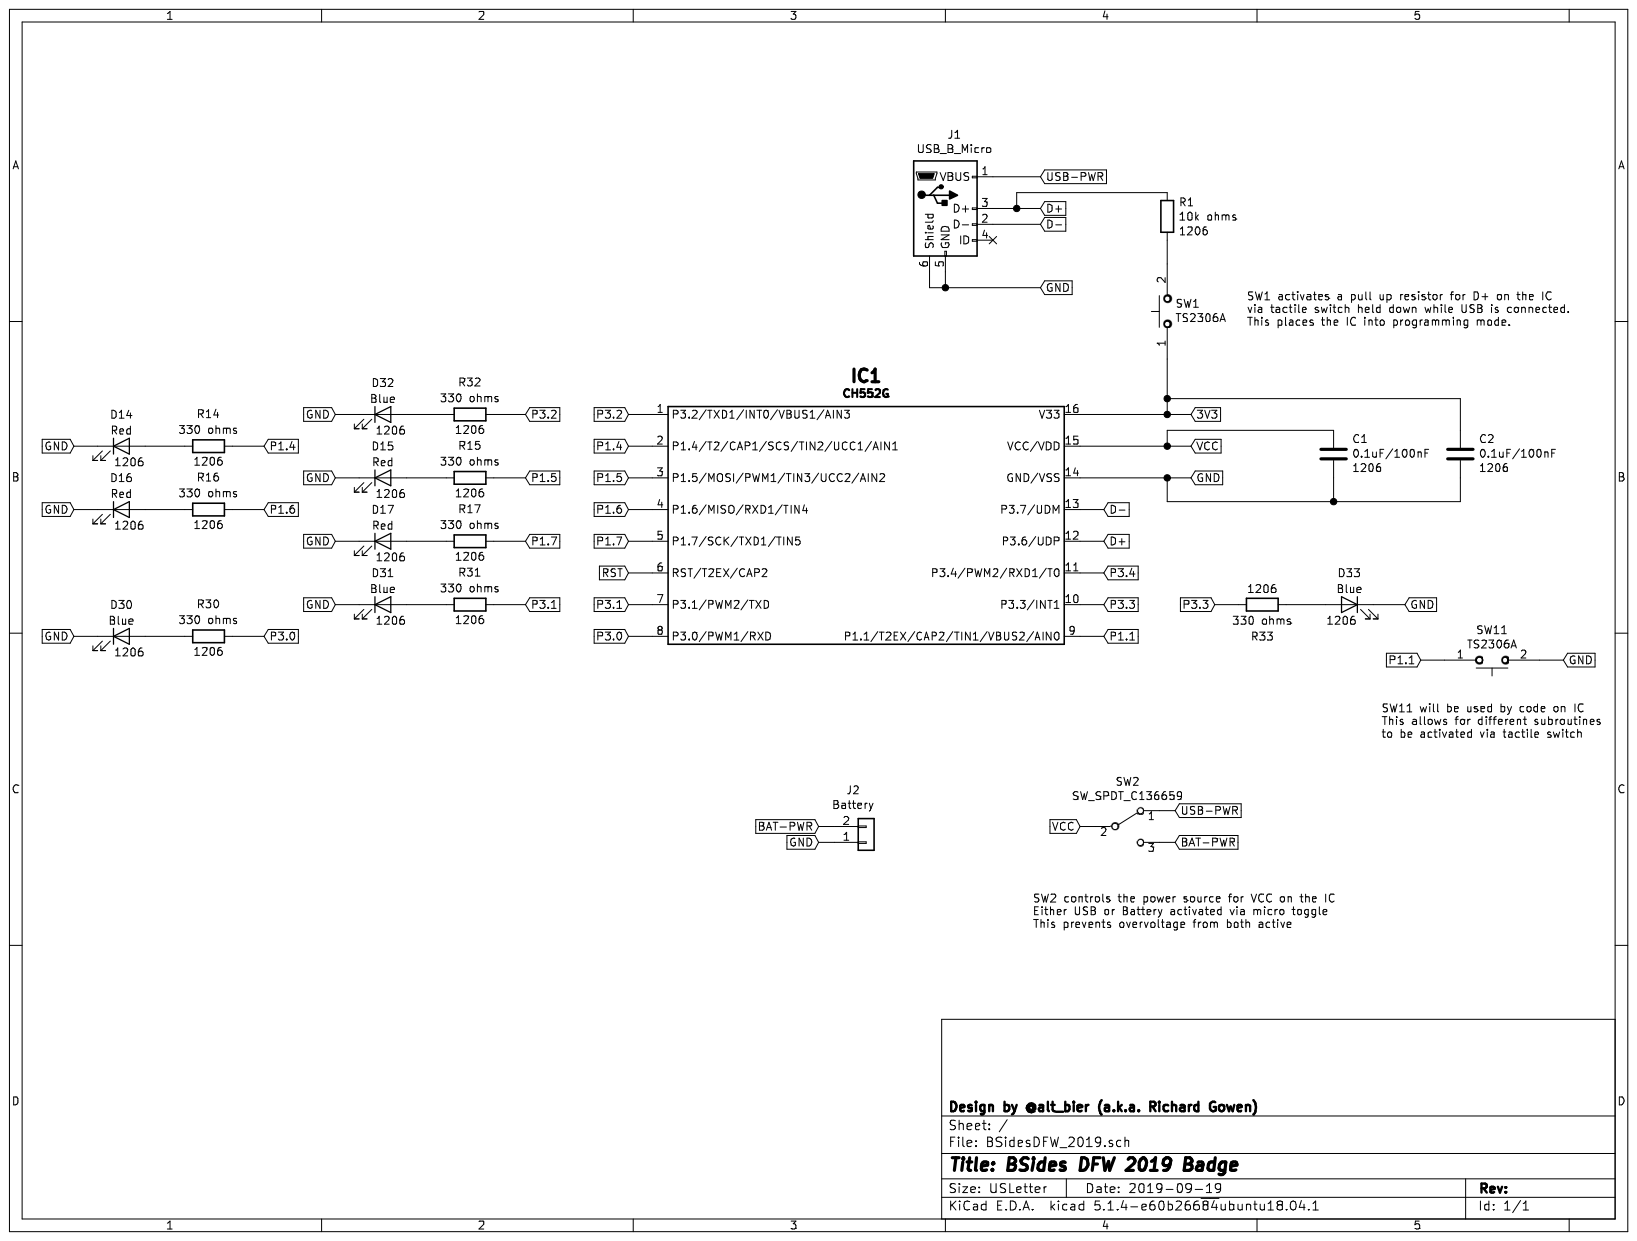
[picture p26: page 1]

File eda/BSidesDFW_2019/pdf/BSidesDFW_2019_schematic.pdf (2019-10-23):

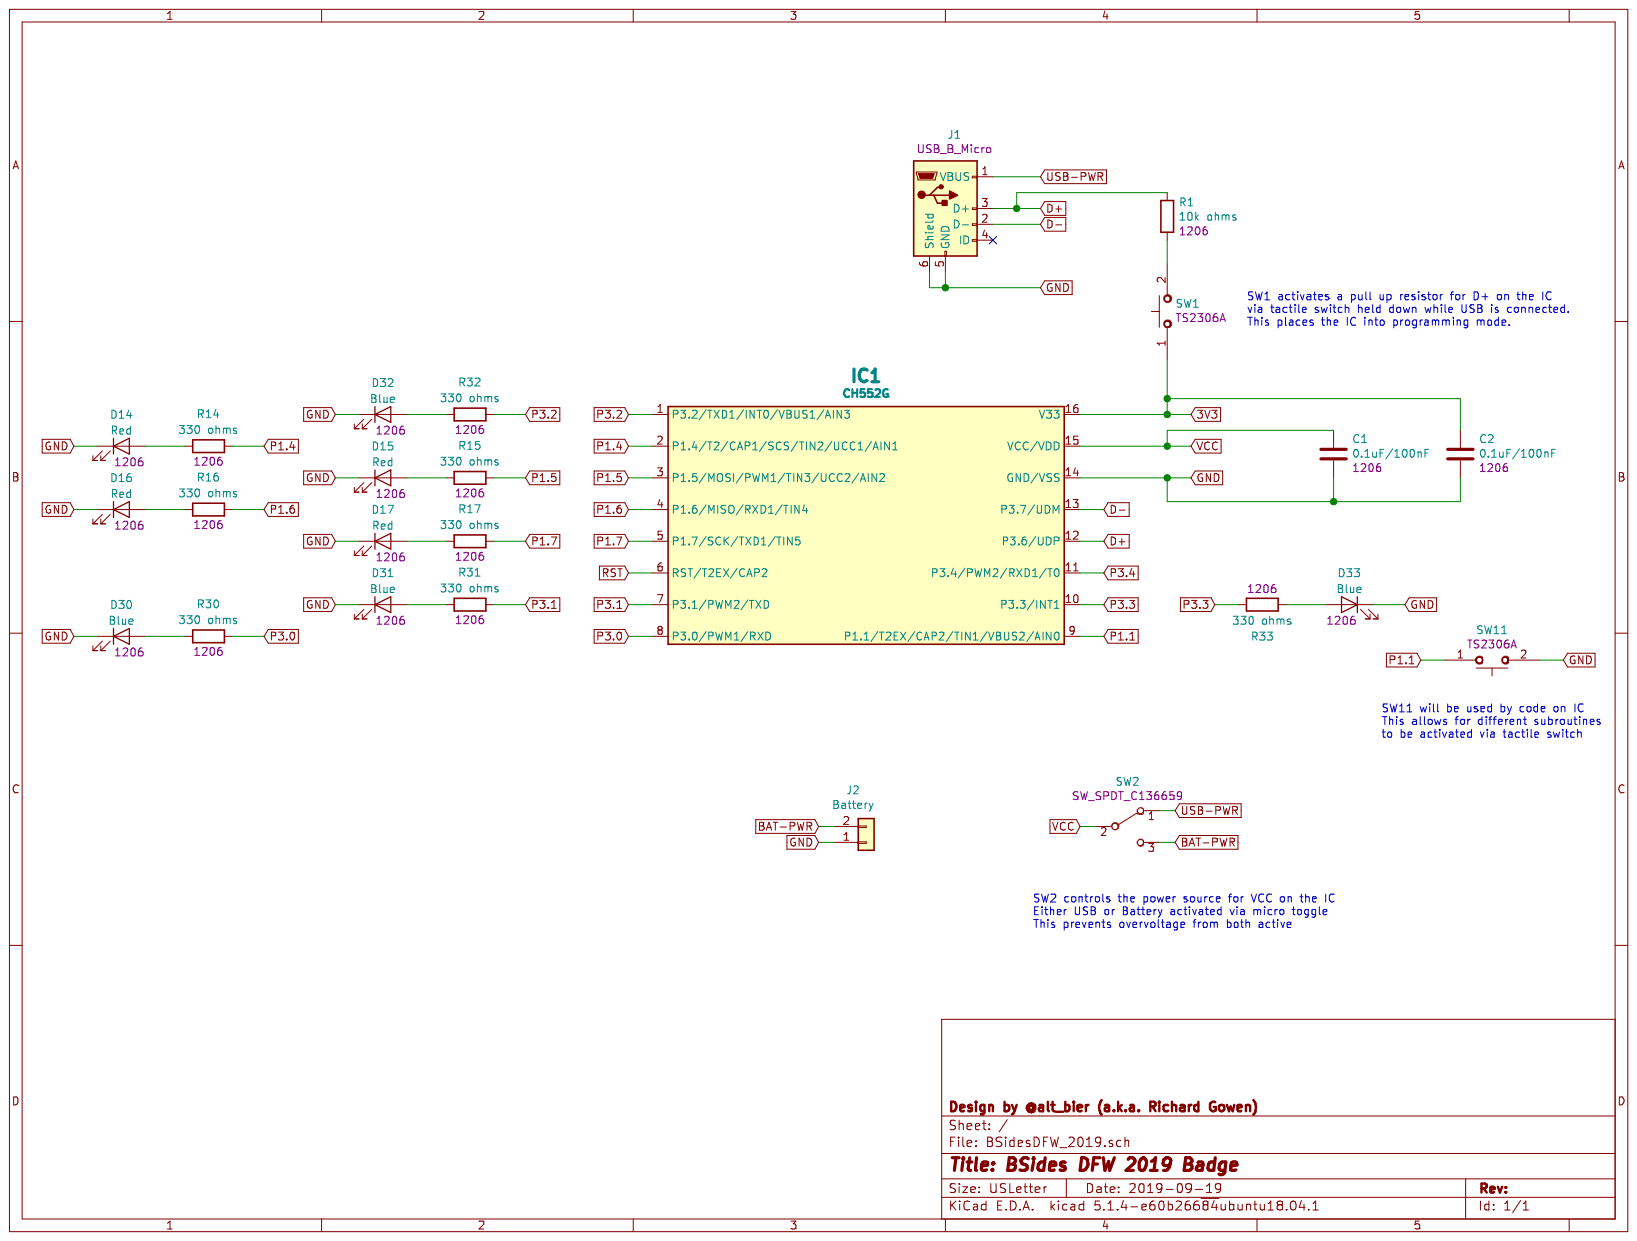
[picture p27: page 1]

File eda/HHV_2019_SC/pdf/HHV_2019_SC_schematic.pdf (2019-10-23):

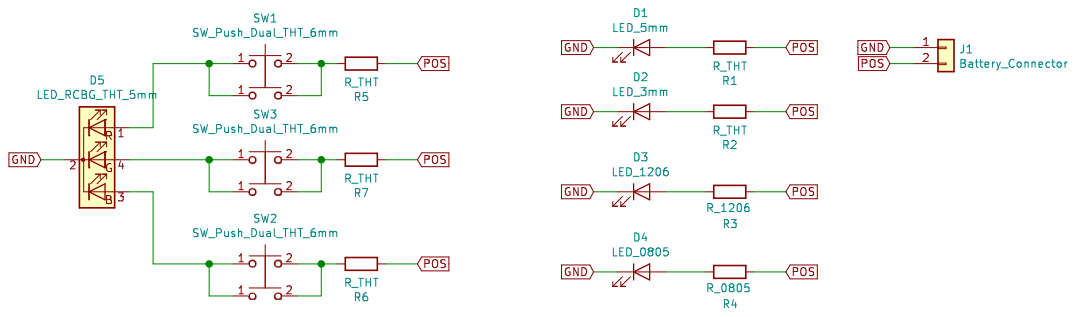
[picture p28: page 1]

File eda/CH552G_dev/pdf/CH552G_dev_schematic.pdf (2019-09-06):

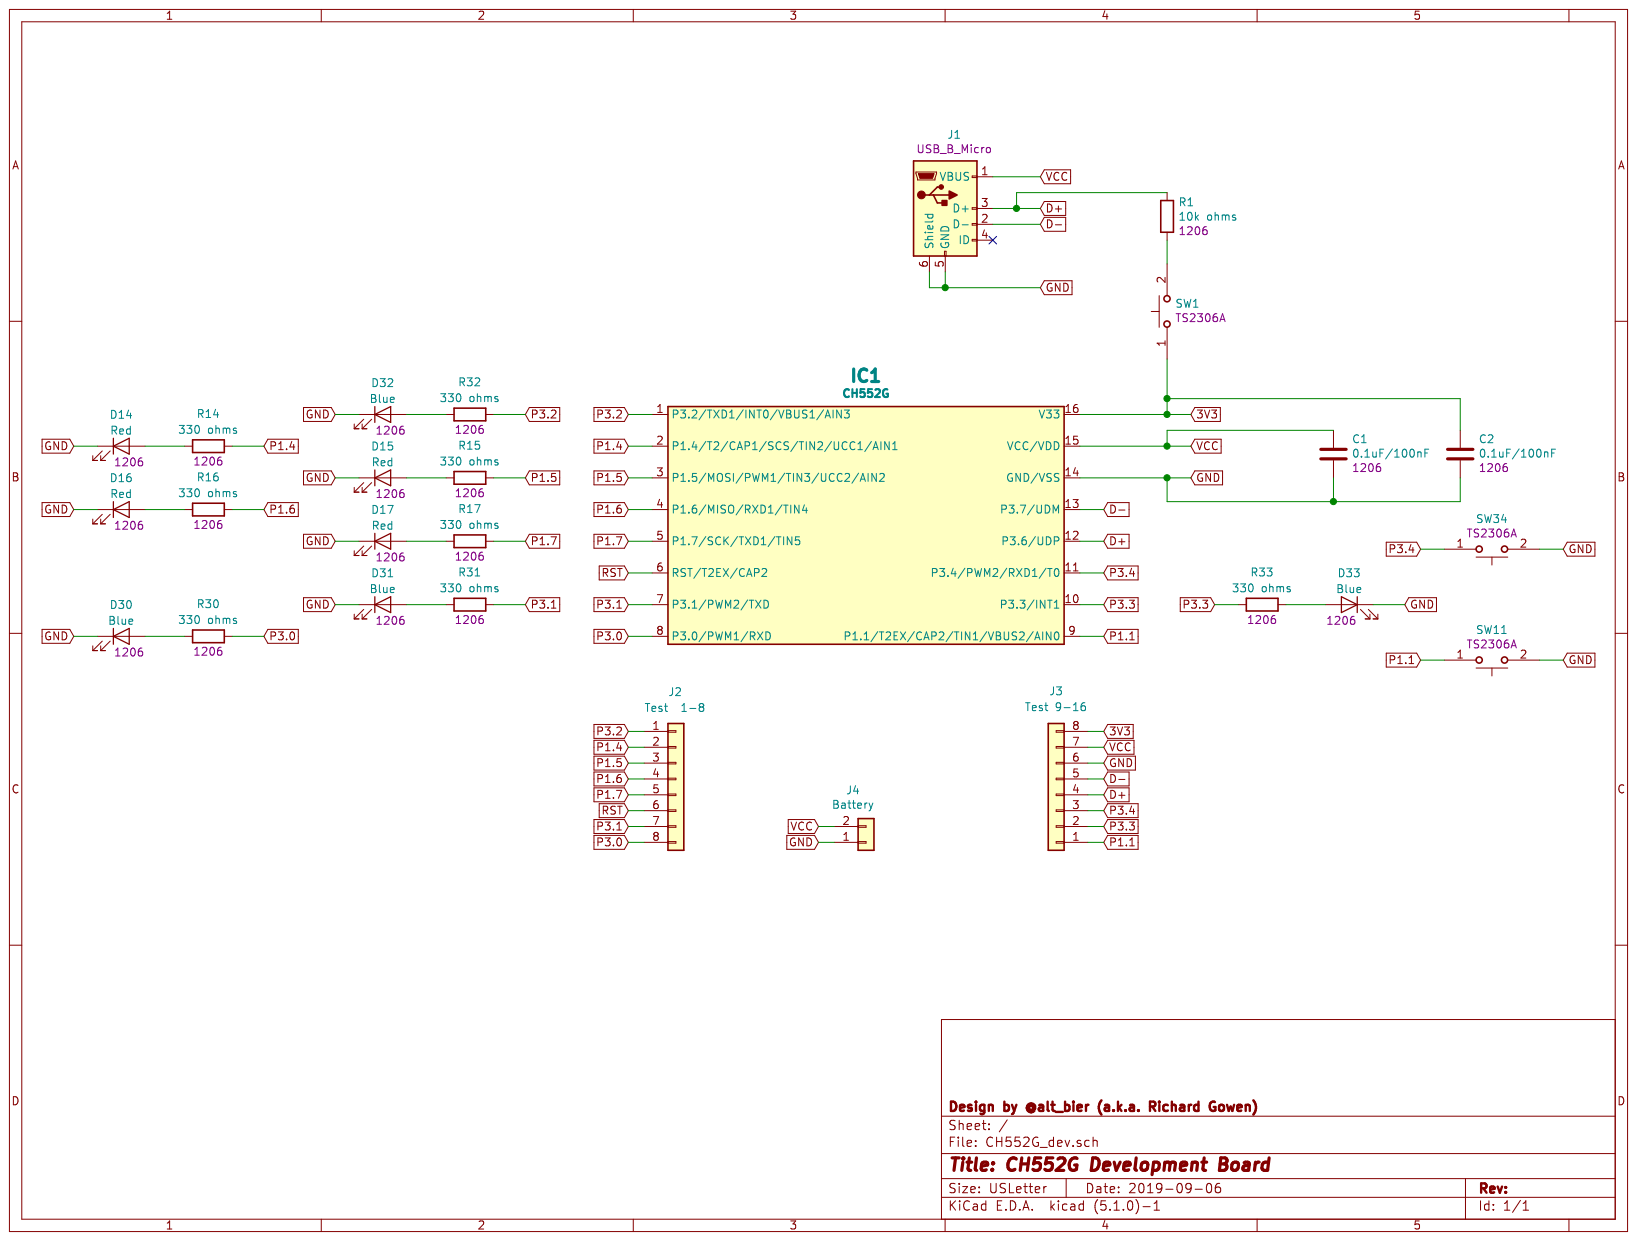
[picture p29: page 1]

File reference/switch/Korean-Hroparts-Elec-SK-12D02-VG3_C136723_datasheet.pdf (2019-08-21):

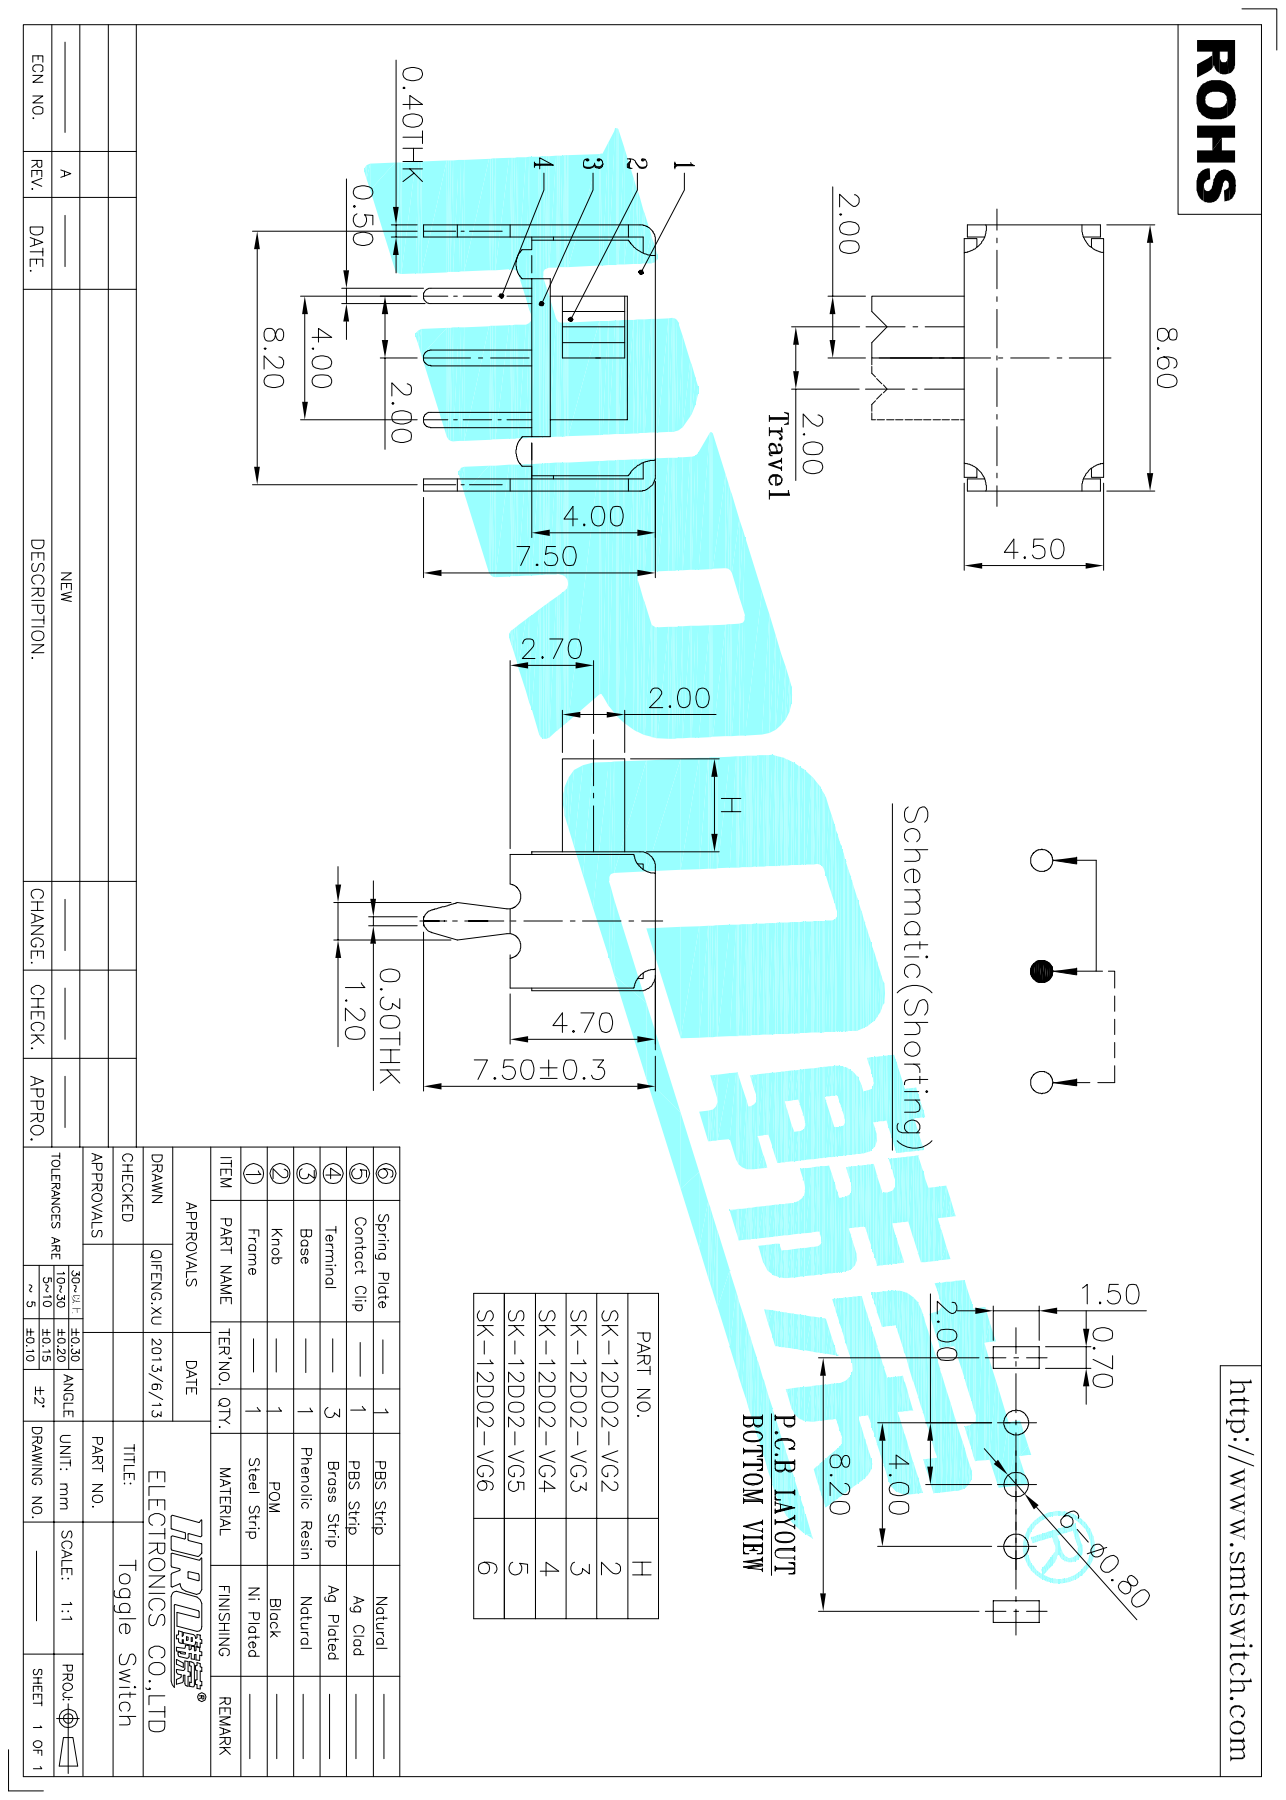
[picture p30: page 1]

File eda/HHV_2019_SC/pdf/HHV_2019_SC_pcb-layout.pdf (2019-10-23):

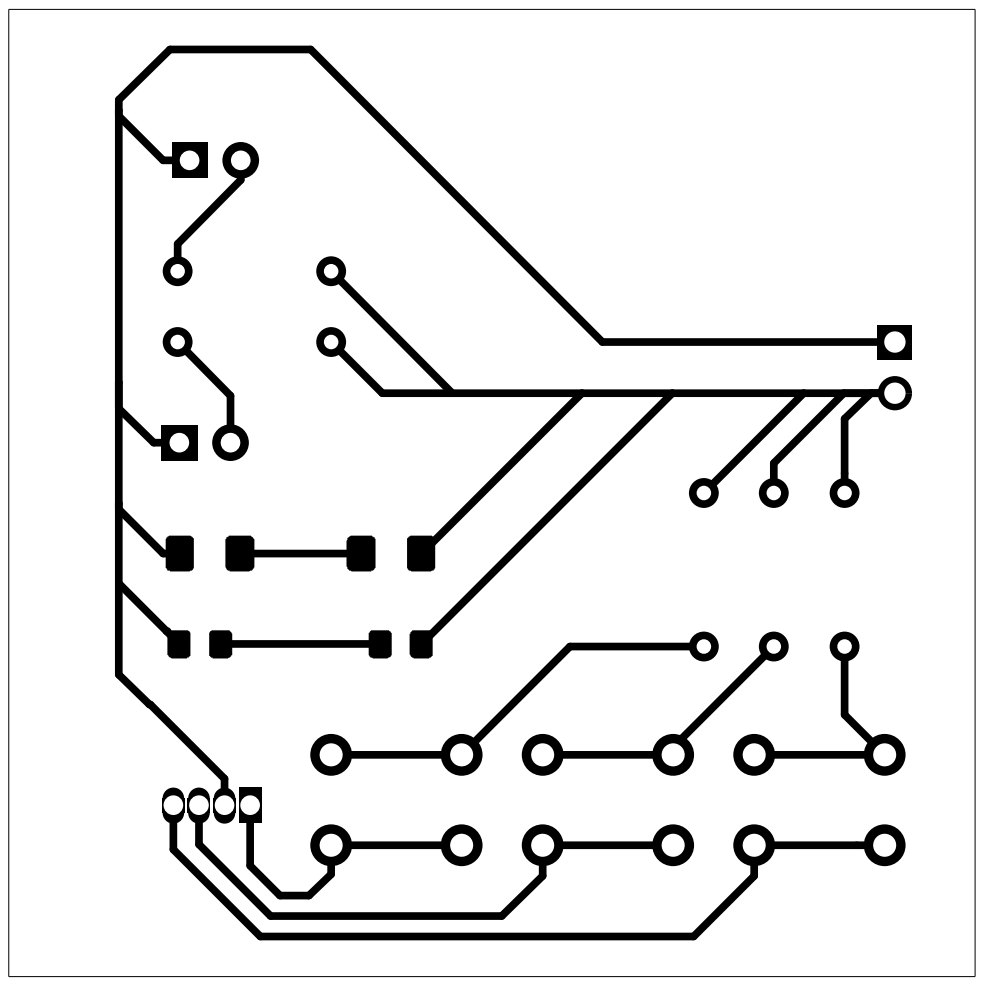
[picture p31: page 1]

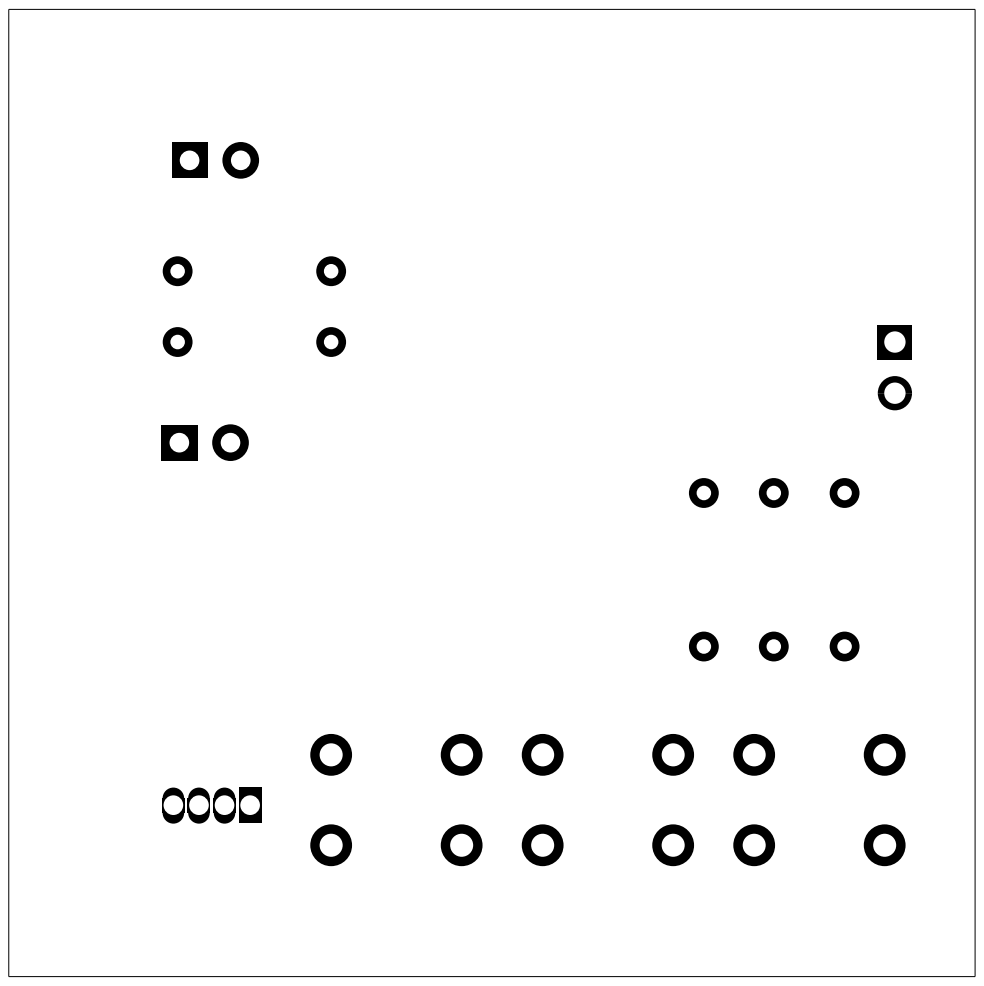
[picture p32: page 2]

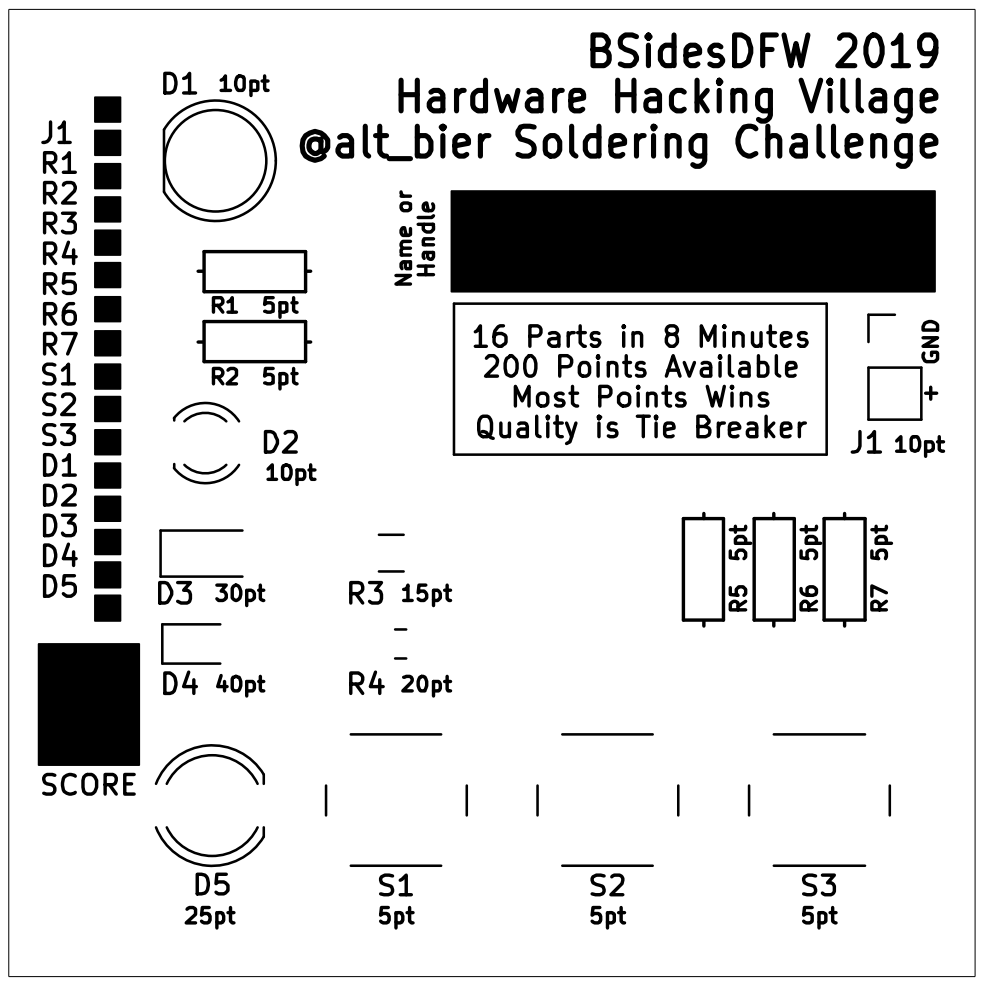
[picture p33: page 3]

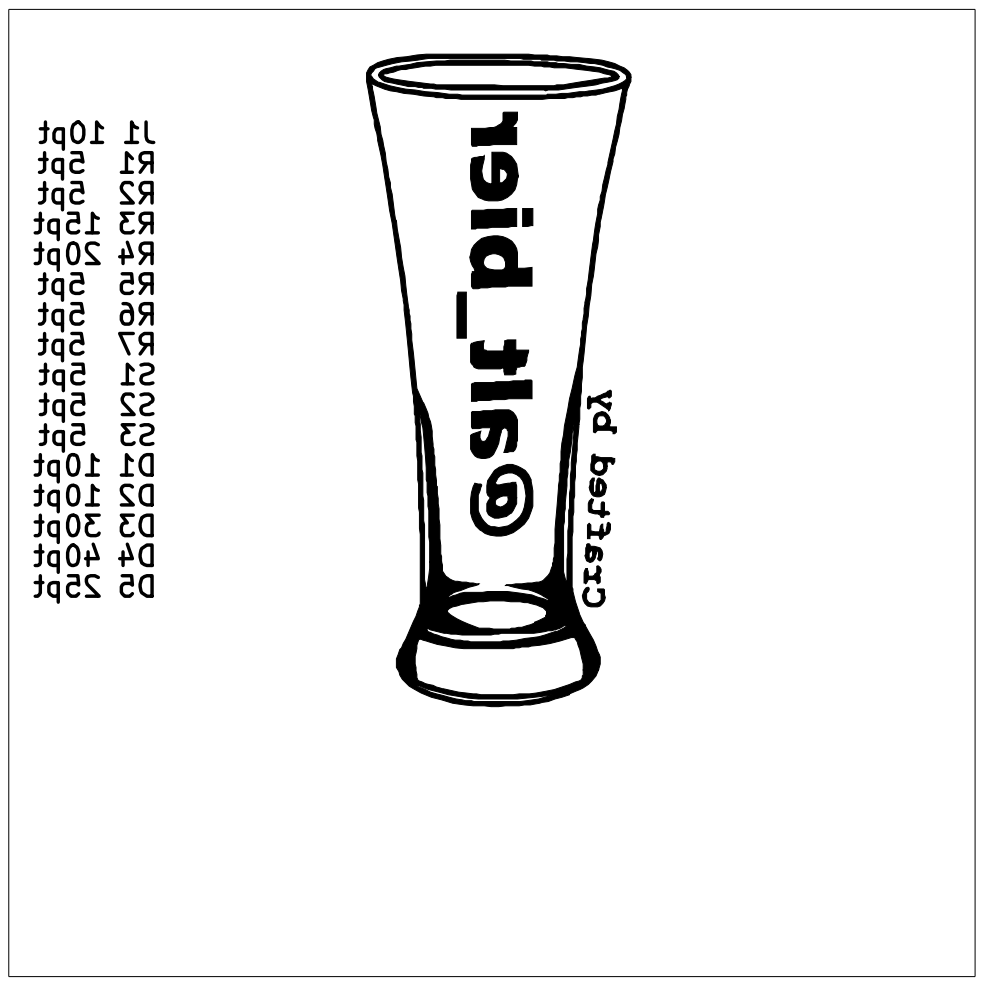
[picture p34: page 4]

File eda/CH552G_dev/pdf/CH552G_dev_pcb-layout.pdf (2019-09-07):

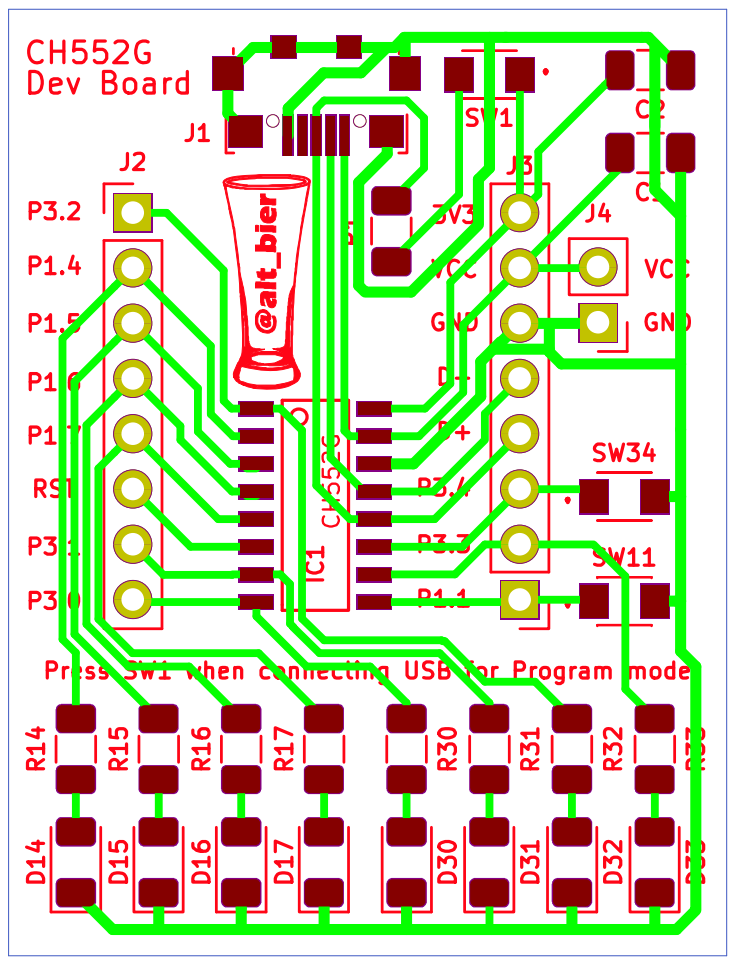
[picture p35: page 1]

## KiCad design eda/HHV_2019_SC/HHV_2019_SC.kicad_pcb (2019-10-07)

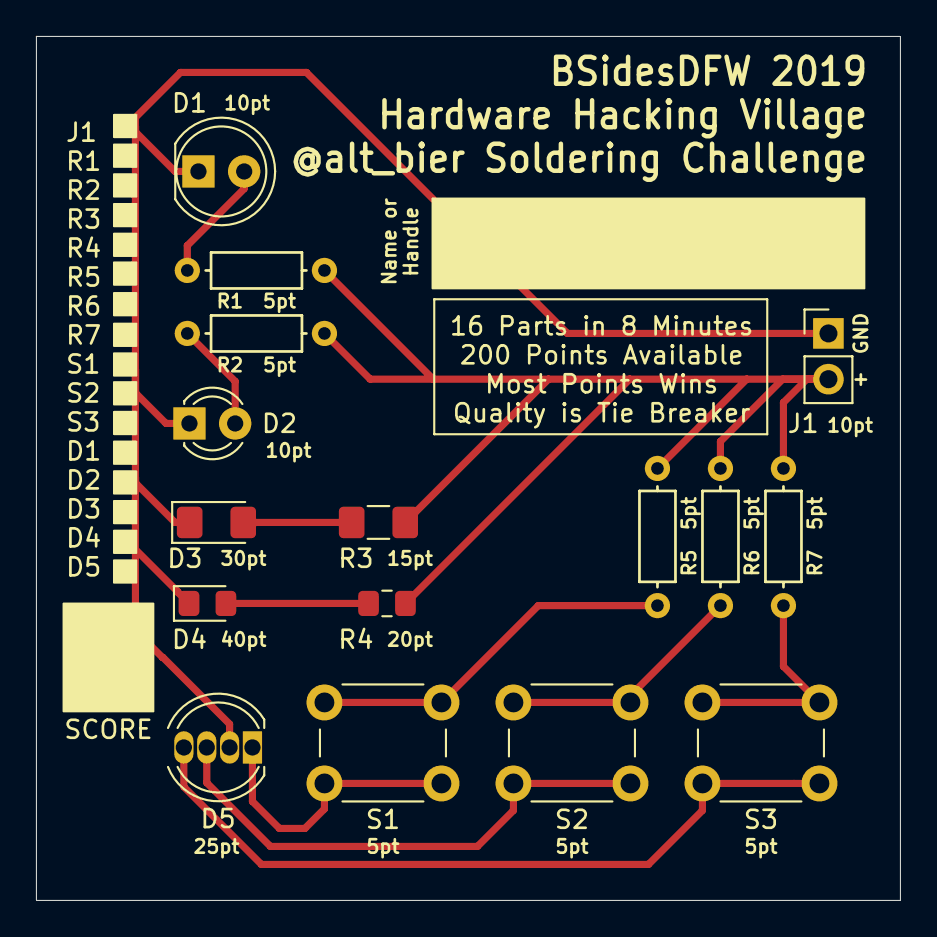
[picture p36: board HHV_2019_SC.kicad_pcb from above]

Board: 2 copper layers, 48.0 x 48.0 mm, 16 parts (0 on the bottom side), 12 nets.

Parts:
D1: LED_5mm; LED_D5.0mm
D2: LED_3mm; LED_D3.0mm
D3: LED_1206; LED_1206_3216Metric_Pad1.42x1.75mm_HandSolder
D4: LED_0805; LED_0805_2012Metric_Pad1.15x1.40mm_HandSolder
D5: LED_RCBG_THT_5mm; LED_D5.0mm-4_RGB
J1: Battery_Connector; Pin_Header_Straight_1x02_Pitch2.54mm
R1, R2, R5, R6, R7: R_THT; R_Axial_DIN0207_L6.3mm_D2.5mm_P7.62mm_Horizontal
R3: R_1206; R_1206_3216Metric_Pad1.42x1.75mm_HandSolder
R4: R_0805; R_0805_2012Metric_Pad1.15x1.40mm_HandSolder
S1, S2, S3: SW_Push_Dual_THT_6mm; SW_PUSH_6mm

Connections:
GND: D1.1, D2.1, D3.1, D4.1, D5.2, J1.1
unnamed: D1.2, R1.2
unnamed: D2.2, R2.2
unnamed: D3.2, R3.2
unnamed: D4.2, R4.2
unnamed: D5.1, S1.1
unnamed: D5.3, S2.1
unnamed: D5.4, S3.1
unnamed: R5.2, S1.2
unnamed: R6.2, S2.2
unnamed: R7.2, S3.2
POS: J1.2, R1.1, R2.1, R3.1, R4.1, R5.1, R6.1, R7.1

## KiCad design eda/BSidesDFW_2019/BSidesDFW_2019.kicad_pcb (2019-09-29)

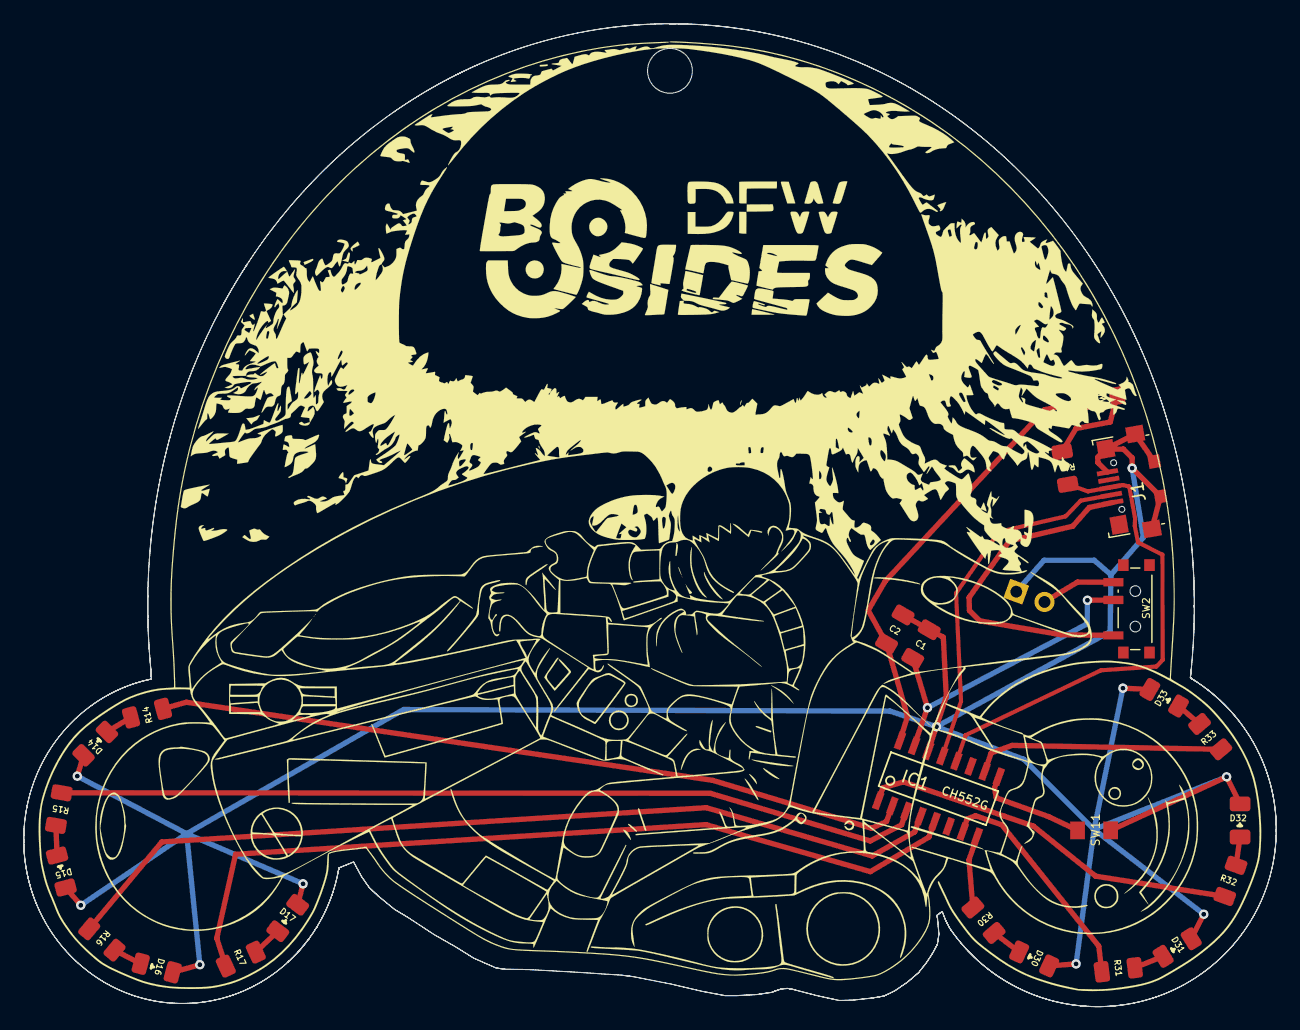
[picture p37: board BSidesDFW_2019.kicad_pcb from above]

Board: 2 copper layers, 105.9 x 83.1 mm, 25 parts (0 on the bottom side), 25 nets.

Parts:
C1, C2: 0.1uF/100nF; C_1206_3216Metric
D14, D15, D16, D17: Red; LED_1206_3216Metric
D30, D31, D32, D33: Blue; LED_1206_3216Metric
IC1: CH552G; SOIC-16_3.9x9.9mm_Pitch1.27mm
J1: USB_B_Micro; USB_Micro-B_Jing
J2: Battery; Pin_Header_Straight_1x02_Pitch2.54mm
R1: 10k ohms; R_1206_3216Metric
R14, R15, R16, R17, R30, R31, R32, R33: 330 ohms; R_1206_3216Metric
SW1, SW11: TS2306A; TS2306A240GFMSM9_C388290
SW2: SW_SPDT_C136659; SW_SPDT_PCM12_C136659

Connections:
3V3: C2.2, IC1.16, SW1.1
BAT-PWR: J2.2, SW2.3
D+: IC1.12, J1.3, R1.1
D-: IC1.13, J1.2
GND: C1.1, C2.1, D14.1, D15.1, D16.1, D17.1, D30.1, D31.1, D32.1, D33.1, IC1.14, J1.5, J1.6, J2.1, SW11.2
unnamed: D14.2, R14.1
unnamed: D15.2, R15.1
unnamed: D16.2, R16.1
unnamed: D17.2, R17.1
unnamed: D30.2, R30.1
unnamed: D31.2, R31.1
unnamed: D32.2, R32.1
unnamed: D33.2, R33.1
unnamed: R1.2, SW1.2
P1.1: IC1.9, SW11.1
P1.4: IC1.2, R14.2
P1.5: IC1.3, R15.2
P1.6: IC1.4, R16.2
P1.7: IC1.5, R17.2
P3.0: IC1.8, R30.2
P3.1: IC1.7, R31.2
P3.2: IC1.1, R32.2
P3.3: IC1.10, R33.2
USB-PWR: J1.1, SW2.1
VCC: C1.2, IC1.15, SW2.2

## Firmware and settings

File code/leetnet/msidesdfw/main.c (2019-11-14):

// Chase LEDs in two groups
// LEDs connected to pins 1.4, 1.5, 1.6, 1.7, 3.0, 3.1, 3.2, 3.3
// Tactile switch connected to pin 1.1

#include <ch554.h>
#include <debug.h>

#define LED30_PIN 0
#define LED31_PIN 1
#define LED32_PIN 2
#define LED33_PIN 3
#define LED14_PIN 4
#define LED15_PIN 5
#define LED16_PIN 6
#define LED17_PIN 7

#define BUTTON11_PIN 1

// P1 = 0x90 P3 = 0xB0
SBIT(LED30, 0xB0, LED30_PIN);
SBIT(LED31, 0xB0, LED31_PIN);
SBIT(LED32, 0xB0, LED32_PIN);
SBIT(LED33, 0xB0, LED33_PIN);
SBIT(LED14, 0x90, LED14_PIN);
SBIT(LED15, 0x90, LED15_PIN);
SBIT(LED16, 0x90, LED16_PIN);
SBIT(LED17, 0x90, LED17_PIN);

SBIT(BUTTON11, 0x90, BUTTON11_PIN);

int i=0;
int count=0;
int bright=350;
int inhale=1250;
int pulse=3571;
int rest=1000;

// 1 byte integer for putton push flag - no bool type available
uint8_t button11push=0;
// 1 byte integer for LED Mode (controlled by button)
// Modes 1 thru 4 are chase at different speeds, Mode 5 is cryto challenge
uint8_t ledmode=1;

void main() {
    CfgFsys();

    // Configure pin 3.0 as GPIO output
    P3_MOD_OC = P3_MOD_OC & ~(1<<LED30_PIN);
    P3_DIR_PU = P3_DIR_PU |	(1<<LED30_PIN);
    // Configure pin 3.1 as GPIO output
    P3_MOD_OC = P3_MOD_OC & ~(1<<LED31_PIN);
    P3_DIR_PU = P3_DIR_PU |	(1<<LED31_PIN);
    // Configure pin 3.0 as GPIO output
    P3_MOD_OC = P3_MOD_OC & ~(1<<LED32_PIN);
    P3_DIR_PU = P3_DIR_PU |	(1<<LED32_PIN);
    // Configure pin 3.1 as GPIO output
    P3_MOD_OC = P3_MOD_OC & ~(1<<LED33_PIN);
    P3_DIR_PU = P3_DIR_PU |	(1<<LED33_PIN);

    // Configure pin 1.4 as GPIO output
    P1_MOD_OC = P1_MOD_OC & ~(1<<LED14_PIN);
    P1_DIR_PU = P1_DIR_PU |	(1<<LED14_PIN);
    // Configure pin 1.5 as GPIO output
    P1_MOD_OC = P1_MOD_OC & ~(1<<LED15_PIN);
    P1_DIR_PU = P1_DIR_PU |	(1<<LED15_PIN);
    // Configure pin 1.6 as GPIO output
    P1_MOD_OC = P1_MOD_OC & ~(1<<LED16_PIN);
    P1_DIR_PU = P1_DIR_PU |	(1<<LED16_PIN);
    // Configure pin 1.7 as GPIO output
    P1_MOD_OC = P1_MOD_OC & ~(1<<LED17_PIN);
    P1_DIR_PU = P1_DIR_PU |	(1<<LED17_PIN);

    // All LEDs start with a value of 1 which is ON
    // Turn ALL OFF to start
    LED30 = 0;  // OFF
    LED31 = 0;  // OFF
    LED32 = 0;  // OFF
    LED33 = 0;  // OFF
    LED14 = 0;  // OFF
    LED15 = 0;  // OFF
    LED16 = 0;  // OFF
    LED17 = 0;  // OFF
    while (1) {

      if (ledmode < 5) //rolling mode, 1-4
      {
        // Delay controls speed
        mDelaymS(40 * ledmode);
        // Button starts as TRUE 1 and pulls down to FALSE 0 when pushed
        // If we see button push set button push flag
        if (BUTTON11 == 0) { button11push = 1; }
        // Turn off previous two, turn on next two
        LED33 = 0;  // OFF
        LED30 = 1;  // ON
        LED17 = 0;  // OFF
        LED14 = 1;  // ON
        // Delay controls speed
      	mDelaymS(40 * ledmode);
        // Button starts as TRUE 1 and pulls down to FALSE 0 when pushed
        // If we see button push set button push flag
        if (BUTTON11 == 0) { button11push = 1; }
        // Turn off previous two, turn on next two
        LED30 = 0;  // OFF
        LED31 = 1;  // ON
        LED14 = 0;  // OFF
        LED15 = 1;  // ON
        // Delay controls speed
        mDelaymS(40 * ledmode);
        // Button starts as TRUE 1 and pulls down to FALSE 0 when pushed
        // If we see button push set button push flag
        if (BUTTON11 == 0) { button11push = 1; }
        // Turn off previous two, turn on next two
        LED31 = 0;  // OFF
        LED32 = 1;  // ON
        LED15 = 0;  // OFF
        LED16 = 1;  // ON
        // Delay controls speed
        mDelaymS(40 * ledmode);
        // Button starts as TRUE 1 and pulls down to FALSE 0 when pushed
        // If we see button push set button push flag
        if (BUTTON11 == 0) { button11push = 1; }
        // Turn off previous two, turn on next two
        LED32 = 0;  // OFF
        LED33 = 1;  // ON
        LED16 = 0;  // OFF
        LED17 = 1;  // ON
      }
      if (ledmode == 5) //single LED walking pulse
      {
        LED30 = 0;  // OFF
        LED31 = 0;  // OFF
        LED32 = 0;  // OFF
        LED33 = 0;  // OFF
        LED14 = 0;  // OFF
        LED15 = 0;  // OFF
        LED16 = 0;  // OFF
        LED17 = 0;  // OFF
	
        for( count = 0; count < 8; count = count + 1 ){
            if (BUTTON11 == 0) { button11push = 1; }
	    for( i = 1; i < bright; i = i + 1 ){
                if (count == 0) {LED14 = 1;}
                if (count == 1) {LED15 = 1;}
                if (count == 2) {LED16 = 1;}
                if (count == 3) {LED17 = 1;}
                if (count == 4) {LED30 = 1;}
                if (count == 5) {LED31 = 1;}
                if (count == 6) {LED32 = 1;}
                if (count == 7) {LED33 = 1;}
                mDelayuS(i*10);
                if (count == 0) {LED14 = 0;}
                if (count == 1) {LED15 = 0;}
                if (count == 2) {LED16 = 0;}
                if (count == 3) {LED17 = 0;}
                if (count == 4) {LED30 = 0;}
                if (count == 5) {LED31 = 0;}
                if (count == 6) {LED32 = 0;}
                if (count == 7) {LED33 = 0;}
                mDelayuS(pulse-i*10);
            }
            if (BUTTON11 == 0) { button11push = 1; }
            for( i = bright-1; i>0; i = i - 1 ){
                if (count == 0) {LED14 = 1;}
                if (count == 1) {LED15 = 1;}
                if (count == 2) {LED16 = 1;}
                if (count == 3) {LED17 = 1;}
                if (count == 4) {LED30 = 1;}
                if (count == 5) {LED31 = 1;}
                if (count == 6) {LED32 = 1;}
                if (count == 7) {LED33 = 1;}
                mDelayuS(i*10);
                if (count == 0) {LED14 = 0;}
                if (count == 1) {LED15 = 0;}
                if (count == 2) {LED16 = 0;}
                if (count == 3) {LED17 = 0;}
                if (count == 4) {LED30 = 0;}
                if (count == 5) {LED31 = 0;}
                if (count == 6) {LED32 = 0;}
                if (count == 7) {LED33 = 0;}
                mDelayuS(pulse-i*10);
            }
	    if (BUTTON11 == 0) { button11push = 1; }
        }
      }
      if (ledmode == 6) //led walking pulse, group die off
      {
	for( count = 0; count < 8; count = count + 1 ){
            if (BUTTON11 == 0) { button11push = 1; }
	    for( i = 1; i < bright; i = i + 1 ){
                if (count == 0) {LED14 = 1;}
                if (count == 1) {LED15 = 1;}
                if (count == 2) {LED16 = 1;}
                if (count == 3) {LED17 = 1;}
                if (count == 4) {LED30 = 1;}
                if (count == 5) {LED31 = 1;}
                if (count == 6) {LED32 = 1;}
                if (count == 7) {LED33 = 1;}
                mDelayuS(i*10);
                if (count == 0) {LED14 = 0;}
                if (count == 1) {LED15 = 0;}
                if (count == 2) {LED16 = 0;}
                if (count == 3) {LED17 = 0;}
                if (count == 4) {LED30 = 0;}
                if (count == 5) {LED31 = 0;}
                if (count == 6) {LED32 = 0;}
                if (count == 7) {LED33 = 0;}
                mDelayuS(pulse-i*10);
            }
            if (BUTTON11 == 0) { button11push = 1; }
            for( i = bright-1; i>0; i = i - 1 ){
                LED14 = 1;  // ON
                LED15 = 1;  // ON
                LED16 = 1;  // ON
                LED17 = 1;  // ON
                LED30 = 1;  // ON
                LED31 = 1;  // ON
                LED32 = 1;  // ON
                LED33 = 1;  // ON
                mDelayuS(i*10);
                LED14 = 0;  // OFF
                LED15 = 0;  // OFF
                LED16 = 0;  // OFF
                LED17 = 0;  // OFF
                LED30 = 0;  // OFF
                LED31 = 0;  // OFF
                LED32 = 0;  // OFF
                LED33 = 0;  // OFF
                mDelayuS(pulse-i*10);
            }
	    if (BUTTON11 == 0) { button11push = 1; }
        }
      }
      if (ledmode == 7) //fracking cylons
      {
	if (BUTTON11 == 0) { button11push = 1; }
	//go there
        LED14 = 1;  // OFF
        LED15 = 0;  // OFF
        LED16 = 0;  // OFF
        LED17 = 0;  // OFF
        LED30 = 0;  // OFF
        LED31 = 0;  // OFF
        LED32 = 0;  // OFF
        LED33 = 0;  // OFF
        mDelaymS(150);
	if (BUTTON11 == 0) { button11push = 1; }
        LED14 = 0;  // OFF
        LED15 = 1;  // OFF
        LED16 = 0;  // OFF
        LED17 = 0;  // OFF
        LED30 = 0;  // OFF
        LED31 = 0;  // OFF
        LED32 = 0;  // OFF
        LED33 = 0;  // OFF
        mDelaymS(150);
	if (BUTTON11 == 0) { button11push = 1; }
        LED14 = 0;  // OFF
        LED15 = 0;  // OFF
        LED16 = 1;  // OFF
        LED17 = 0;  // OFF
        LED30 = 0;  // OFF
        LED31 = 0;  // OFF
        LED32 = 0;  // OFF
        LED33 = 0;  // OFF
        mDelaymS(150);
	if (BUTTON11 == 0) { button11push = 1; }
        LED14 = 0;  // OFF
        LED15 = 0;  // OFF
        LED16 = 0;  // OFF
        LED17 = 1;  // OFF
        LED30 = 0;  // OFF
        LED31 = 0;  // OFF
        LED32 = 0;  // OFF
        LED33 = 0;  // OFF
        mDelaymS(150);
	if (BUTTON11 == 0) { button11push = 1; }
        LED14 = 0;  // OFF
        LED15 = 0;  // OFF
        LED16 = 0;  // OFF
        LED17 = 0;  // OFF
        LED30 = 0;  // OFF
        LED31 = 0;  // OFF
        LED32 = 0;  // OFF
        LED33 = 0;  // OFF
        mDelaymS(150);
	if (BUTTON11 == 0) { button11push = 1; }
        LED14 = 0;  // OFF
        LED15 = 0;  // OFF
        LED16 = 0;  // OFF
        LED17 = 0;  // OFF
        LED30 = 1;  // OFF
        LED31 = 0;  // OFF
        LED32 = 0;  // OFF
        LED33 = 0;  // OFF
        mDelaymS(150);
	if (BUTTON11 == 0) { button11push = 1; }
        LED14 = 0;  // OFF
        LED15 = 0;  // OFF
        LED16 = 0;  // OFF
        LED17 = 0;  // OFF
        LED30 = 0;  // OFF
        LED31 = 1;  // OFF
        LED32 = 0;  // OFF
        LED33 = 0;  // OFF
        mDelaymS(150);
	if (BUTTON11 == 0) { button11push = 1; }
        LED14 = 0;  // OFF
        LED15 = 0;  // OFF
        LED16 = 0;  // OFF
        LED17 = 0;  // OFF
        LED30 = 0;  // OFF
        LED31 = 0;  // OFF
        LED32 = 1;  // OFF
        LED33 = 0;  // OFF
        mDelaymS(150);
	if (BUTTON11 == 0) { button11push = 1; }
        LED14 = 0;  // OFF
        LED15 = 0;  // OFF
        LED16 = 0;  // OFF
        LED17 = 0;  // OFF
        LED30 = 0;  // OFF
        LED31 = 0;  // OFF
        LED32 = 0;  // OFF
        LED33 = 1;  // OFF
        //and back again
        mDelaymS(250);
	if (BUTTON11 == 0) { button11push = 1; }
        LED14 = 0;  // OFF
        LED15 = 0;  // OFF
        LED16 = 0;  // OFF
        LED17 = 0;  // OFF
        LED30 = 0;  // OFF
        LED31 = 0;  // OFF
        LED32 = 1;  // OFF
        LED33 = 0;  // OFF
        mDelaymS(150);
	if (BUTTON11 == 0) { button11push = 1; }
        LED14 = 0;  // OFF
        LED15 = 0;  // OFF
        LED16 = 0;  // OFF
        LED17 = 0;  // OFF
        LED30 = 0;  // OFF
        LED31 = 1;  // OFF
        LED32 = 0;  // OFF
        LED33 = 0;  // OFF
        mDelaymS(150);
	if (BUTTON11 == 0) { button11push = 1; }
        LED14 = 0;  // OFF
        LED15 = 0;  // OFF
        LED16 = 0;  // OFF
        LED17 = 0;  // OFF
        LED30 = 1;  // OFF
        LED31 = 0;  // OFF
        LED32 = 0;  // OFF
        LED33 = 0;  // OFF
        mDelaymS(150);
	if (BUTTON11 == 0) { button11push = 1; }
        LED14 = 0;  // OFF
        LED15 = 0;  // OFF
        LED16 = 0;  // OFF
        LED17 = 0;  // OFF
        LED30 = 0;  // OFF
        LED31 = 0;  // OFF
        LED32 = 0;  // OFF
        LED33 = 0;  // OFF
        mDelaymS(150);
	if (BUTTON11 == 0) { button11push = 1; }
        LED14 = 0;  // OFF
        LED15 = 0;  // OFF
        LED16 = 0;  // OFF
        LED17 = 1;  // OFF
        LED30 = 0;  // OFF
        LED31 = 0;  // OFF
        LED32 = 0;  // OFF
        LED33 = 0;  // OFF
        mDelaymS(150);
	if (BUTTON11 == 0) { button11push = 1; }
        LED14 = 0;  // OFF
        LED15 = 0;  // OFF
        LED16 = 1;  // OFF
        LED17 = 0;  // OFF
        LED30 = 0;  // OFF
        LED31 = 0;  // OFF
        LED32 = 0;  // OFF
        LED33 = 0;  // OFF
        mDelaymS(150);
	if (BUTTON11 == 0) { button11push = 1; }
        LED14 = 0;  // OFF
        LED15 = 1;  // OFF
        LED16 = 0;  // OFF
        LED17 = 0;  // OFF
        LED30 = 0;  // OFF
        LED31 = 0;  // OFF
        LED32 = 0;  // OFF
        LED33 = 0;  // OFF
        mDelaymS(150);
	if (BUTTON11 == 0) { button11push = 1; }
        LED14 = 1;  // OFF
        LED15 = 0;  // OFF
        LED16 = 0;  // OFF
        LED17 = 0;  // OFF
        LED30 = 0;  // OFF
        LED31 = 0;  // OFF
        LED32 = 0;  // OFF
        LED33 = 0;  // OFF
        mDelaymS(250);
	if (BUTTON11 == 0) { button11push = 1; }
      }
      if (ledmode == 8) //group pulsing mode
      {
	if (BUTTON11 == 0) { button11push = 1; }
	for( i = 1; i < bright; i = i + 1 ){
            LED14 = 1;  // ON
            LED15 = 1;  // ON
            LED16 = 1;  // ON
            LED17 = 1;  // ON
            LED30 = 1;  // ON
            LED31 = 1;  // ON
            LED32 = 1;  // ON
            LED33 = 1;  // ON
            mDelayuS(i*10);
            LED14 = 0;  // OFF
            LED15 = 0;  // OFF
            LED16 = 0;  // OFF
            LED17 = 0;  // OFF
            LED30 = 0;  // OFF
            LED31 = 0;  // OFF
            LED32 = 0;  // OFF
            LED33 = 0;  // OFF
            mDelayuS(pulse-i*10);
        }
	if (BUTTON11 == 0) { button11push = 1; }
        for( i = bright-1; i>0; i = i - 1 ){
            LED14 = 1;  // ON
            LED15 = 1;  // ON
            LED16 = 1;  // ON
            LED17 = 1;  // ON
            LED30 = 1;  // ON
            LED31 = 1;  // ON
            LED32 = 1;  // ON
            LED33 = 1;  // ON
            mDelayuS(i*10);
            LED14 = 0;  // OFF
            LED15 = 0;  // OFF
            LED16 = 0;  // OFF
            LED17 = 0;  // OFF
            LED30 = 0;  // OFF
            LED31 = 0;  // OFF
            LED32 = 0;  // OFF
            LED33 = 0;  // OFF
            mDelayuS(pulse-i*10);
        }
	if (BUTTON11 == 0) { button11push = 1; }
      }
      if (ledmode == 9) //flashing mode
      {
        if (BUTTON11 == 0) { button11push = 1; }
        mDelaymS(40 * ledmode);
        LED30 = 0;  // OFF
        LED31 = 0;  // OFF
        LED32 = 0;  // OFF
        LED33 = 0;  // OFF
        LED14 = 0;  // OFF
        LED15 = 0;  // OFF
        LED16 = 0;  // OFF
        LED17 = 0;  // OFF
        if (BUTTON11 == 0) { button11push = 1; }
        mDelaymS(40 * ledmode);
        LED30 = 1;  // ON
        LED31 = 1;  // ON
        LED32 = 1;  // ON
        LED33 = 1;  // ON
        LED14 = 1;  // ON
        LED15 = 1;  // ON
        LED16 = 1;  // ON
        LED17 = 1;  // ON
        if (BUTTON11 == 0) { button11push = 1; }
        mDelaymS(40 * ledmode);
        LED30 = 0;  // OFF
        LED31 = 0;  // OFF
        LED32 = 0;  // OFF
        LED33 = 0;  // OFF
        LED14 = 0;  // OFF
        LED15 = 0;  // OFF
        LED16 = 0;  // OFF
        LED17 = 0;  // OFF
        if (BUTTON11 == 0) { button11push = 1; }
        mDelaymS(40 * ledmode);
        LED30 = 1;  // ON
        LED31 = 1;  // ON
        LED32 = 1;  // ON
        LED33 = 1;  // ON
        LED14 = 1;  // ON
        LED15 = 1;  // ON
        LED16 = 1;  // ON
        LED17 = 1;  // ON

      }
      if (ledmode == 10) //flashing mode
      {
        if (BUTTON11 == 0) { button11push = 1; }
        mDelaymS(40 * ledmode);
        LED14 = 1;  // OFF
        LED15 = 0;  // OFF
        LED16 = 0;  // OFF
        LED17 = 1;  // OFF
        LED30 = 0;  // OFF
        LED31 = 0;  // OFF
        LED32 = 1;  // OFF
        LED33 = 0;  // OFF
        if (BUTTON11 == 0) { button11push = 1; }
        mDelaymS(40 * ledmode);
        LED14 = 0;  // OFF
        LED15 = 1;  // OFF
        LED16 = 0;  // OFF
        LED17 = 0;  // OFF
        LED30 = 1;  // OFF
        LED31 = 0;  // OFF
        LED32 = 0;  // OFF
        LED33 = 1;  // OFF
        if (BUTTON11 == 0) { button11push = 1; }
        mDelaymS(40 * ledmode);
        LED14 = 0;  // OFF
        LED15 = 0;  // OFF
        LED16 = 1;  // OFF
        LED17 = 0;  // OFF
        LED30 = 0;  // OFF
        LED31 = 1;  // OFF
        LED32 = 0;  // OFF
        LED33 = 0;  // OFF
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

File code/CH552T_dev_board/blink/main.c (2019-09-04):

// Blink Yellow and Green LEDs connected to pins 1.4 and 1.6

#include <ch554.h>
#include <debug.h>

#define Y_LED_PIN 3
#define G_LED_PIN 5

// P1 = 0x90 P3 = 0xB0
SBIT(YLED, 0xB0, Y_LED_PIN);
SBIT(GLED, 0xB0, G_LED_PIN);

void main() {
    CfgFsys();

    P1_DIR_PU &= 0x0C;
    // Configure pin 3.3 as GPIO output
    P3_MOD_OC = P3_MOD_OC & ~(1<<Y_LED_PIN);
    P3_DIR_PU = P3_DIR_PU |	(1<<Y_LED_PIN);
    // Configure pin 3.5 as GPIO output
    P3_MOD_OC = P3_MOD_OC & ~(1<<G_LED_PIN);
    P3_DIR_PU = P3_DIR_PU |	(1<<G_LED_PIN);

    YLED = !YLED;

    while (1) {
    	mDelaymS(100);
        YLED = !YLED;
        GLED = !GLED;
    }
}

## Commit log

2019-08-20 Started KiCad layout for prototype PCB
    [ch552-prototype.kicad_pcb, ch552-prototype.sch]
2019-08-27 AAA Battery Holder Reference
2019-09-04 Code fopr the CH552T dev board
2019-09-05 Development board work
    [CH552G_dev.kicad_pcb, CH552G_dev.sch, C_0805_2012Metric.step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]
2019-09-06 More dev board work
    [TS2306A.step, USB_Micro-B_Molex_47346-0001.step]
2019-09-06 Dev board schematic complete and pcb started
    [CH552G_dev.kicad_pcb, CH552G_dev.sch, PinHeader_1x02_P2.54mm_Horizontal.step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]
2019-09-07 CH552G dev board complete
    [CH552G_dev-B_Cu.gbr, CH552G_dev-B_Mask.gbr, CH552G_dev-B_Paste.gbr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]
2019-09-09 Started on the HHV Soldering Challenge PCB
    [C_0805_2012Metric.step, C_1206_3216Metric.step, HHV_2019_SC.kicad_pcb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]
2019-09-09 More work on HHV SC PCB
    [LED_D3.0mm.step, LED_D5.0mm-4_RGB_Neo.step, LED_D5.0mm.step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]
2019-09-09 HHV SC PCB updates
    [HHV_2019_SC.sch, LED_D5.0mm-4_RGB.step, SW_PUSH_6mm.step]
2019-09-14 CH552G Dev board update
    [CH552G_dev-B_Cu.gbr, CH552G_dev-B_Mask.gbr, CH552G_dev-B_Paste.gbr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]
2019-09-18 New code for the CH552G dev board
2019-09-19 Using CH552G_dev as template for BSidesDFW_2019 KiCad PCB design.
    [BSidesDFW_2019.kicad_pcb, BSidesDFW_2019.sch, C_0805_2012Metric.step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]
2019-09-20 Completed edge cuts for badge PCB
    [BSidesDFW_2019.kicad_pcb, badge-edge-cuts.dxf]
2019-09-27 First pass of badge pcb complete
    [BSidesDFW_2019.kicad_pcb, BSidesDFW_2019.sch, SW_SPDT_PCM12.step]
2019-09-27 Final design pass of badge PCB
    [BSidesDFW_2019.kicad_pcb, Battery_Holder_3xAAA_Simple.step]
2019-09-29 Badge PCB Prototypes Ready
    [BSidesDFW_2019-B_Cu.gbr, BSidesDFW_2019-B_Mask.gbr, BSidesDFW_2019-B_SilkS.gbr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]
2019-10-07 Soldering Challenge PCB Complete.
    [Battery_Holder_3xAAA_Simple.step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]
2020-04-29 Dev board code for testing
2023-01-28 old staged files

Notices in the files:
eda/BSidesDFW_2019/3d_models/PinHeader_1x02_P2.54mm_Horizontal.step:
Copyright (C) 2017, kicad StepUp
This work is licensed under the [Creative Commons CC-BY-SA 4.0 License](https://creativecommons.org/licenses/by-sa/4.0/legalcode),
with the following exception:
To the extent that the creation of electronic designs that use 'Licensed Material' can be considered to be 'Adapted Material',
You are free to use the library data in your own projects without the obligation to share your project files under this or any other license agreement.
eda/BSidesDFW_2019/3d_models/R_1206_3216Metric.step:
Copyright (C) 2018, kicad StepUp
